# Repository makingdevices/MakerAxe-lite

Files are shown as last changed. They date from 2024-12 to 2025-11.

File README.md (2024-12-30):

<!-- Improved compatibility of back to top link: See: https://github.com/othneildrew/Best-README-Template/pull/73 -->

<!--
*** Thanks for checking out the Best-README-Template. If you have a suggestion
*** that would make this better, please fork the repo and create a pull request
*** or simply open an issue with the tag "enhancement".
*** Don't forget to give the project a star!
*** Thanks again! Now go create something AMAZING! :D
-->

<!-- PROJECT SHIELDS -->
<!--
*** I'm using markdown "reference style" links for readability.
*** Reference links are enclosed in brackets [ ] instead of parentheses ( ).
*** See the bottom of this document for the declaration of the reference variables
*** for contributors-url, forks-url, etc. This is an optional, concise syntax you may use.
*** https://www.markdownguide.org/basic-syntax/#reference-style-links
-->
[][ig-url]
[][yt-url]
[][sponsor-url]
[][stars-url]
[][issues-url]
[][linkedin-url]

<!-- PROJECT LOGO -->
<br />
<div align="center">
  <a href="https://makingdevices.com/links/">
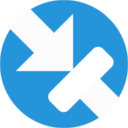
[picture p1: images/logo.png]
    
  </a>

<h3 align="center">Making Devices</h3>

  <p align="center">
    Open Source projects where we struggle with engineering, electronics, coding and who knows what else... MakerAxe-lite is the foundation for new BTC miners and exciting hardware in the future. 
  </p>
</div>

<!-- TABLE OF CONTENTS -->
<details>
  <summary>Table of Contents</summary>
  <ol>
    <li>
      <a href="#about-the-project">About The Project</a>
      <ul>
        <li><a href="#built-with">Built With</a></li>
      </ul>
    </li>
    <li>
      <a href="#Build-one">Build one</a>
      <ul>
      </ul>
    </li>
    <li><a href="#goals">Goals</a></li>
    <li><a href="#features">Features</a></li>
    <li><a href="#roadmap">Roadmap</a></li>
    <li><a href="#license">License</a></li>
    <li><a href="#contact">Contact</a></li>
    <li><a href="#tools">Tools</a></li>
    <li><a href="#Sponsor">Sponsor</a></li>
  </ol>
</details>

<!-- ABOUT THE PROJECT -->
## About The Project

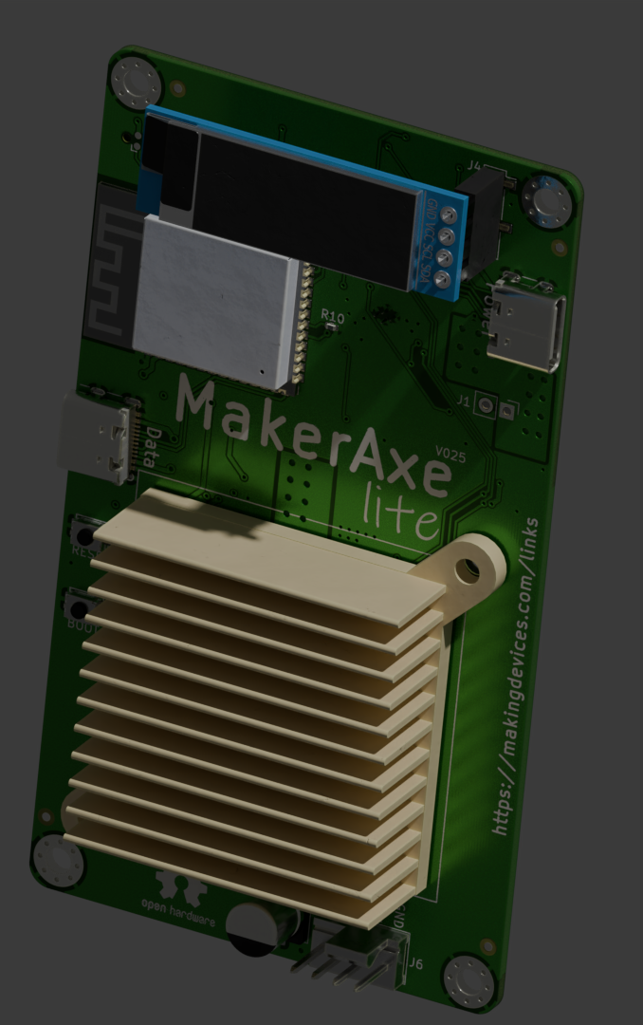
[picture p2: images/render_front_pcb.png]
Bytes Counter Shot
[](https://makingdevices.com/)

```
Open Source is Intrinsic to Bitcoin
```

This is the motto you will see at the top of the [Bitaxe repository](https://github.com/skot/bitaxe), and it’s the reason Why MakerAxe-Lite was created.

MakerAxe Lite is the first attempt to extract the essentials of Bitaxe, reduce it to the minimum, and create a foundation for building new and exciting hardware in the future.

The project modifies the original hardware with the following changes:

1. The screen is not needed, as you now have AxeOS. Therefore, the screen will be removed (DNP) to reduce energy consumption and costs.
2. The 4-layer PCB is reduced to a 2-layer PCB, decreasing the cost of the PCB.
3. The 5V barrel input connector is replaced with USB PD. The voltage (20V, 15V, or 12V) is yet to be decided. This change ensures compatibility with recycled and reused phone or laptop chargers.
4. A LED has been added for blinking status and debug purposes.
5. Software compatibility with the stock [ESP-miner AxeOS](https://github.com/skot/ESP-Miner) (aside from the LED indicator).

<p align="right">(<a href="#readme-top">back to top</a>)</p>

### Built With

[][ESP32-url]

[][kicad-url]
[][sponsor-url]

<p align="right">(<a href="#readme-top">back to top</a>)</p>

<!-- GETTING STARTED -->

## Build one
The project is yet to be finished. Should you want to reproduce it, be careful. 

1. Get the gerber files for the latest version: [MakerAxe-lite V025](/Gerber/makeraxe-litev025.zip) 
2. Send them to a PCB manufacturer ([Our Sponsor is PCBWAY][sponsor-url])
3. Schematic (?)

YET TO BE COMPLETED.

<p align="right">(<a href="#readme-top">back to top</a>)</p>

<!-- GOALS -->
## Goals
- **Standalone**: can mine directly to your pool over WiFi. No External computer needed.
- **Embedded**: low cost, low maintenance, high availability, high reliability, low power.
- **ASIC**: based on the very, very efficient BM1366 from Bitmain.
- **Versatile**: solo/pool mining, autotune power/heat/efficiency.
- **Open Source**: All design files are provided.

<p align="right">(<a href="#readme-top">back to top</a>)</p>

<!-- FEATURES -->
## Features
- **ESP32-S3-WROOM-1** wifi microcontroller on board
- **TI TPS40305** buck regulator steps down the input voltage to power the BM1366
- **Maxim DS4432U+** current DAC digitally adjusts the BM1366 core voltage from 0.04V to 2.4V
- **TI INA260** power meter measures the input voltage and current of the miner
- **Microchip EMC2101** PWM controls the fan and monitors tach output. BM1366 doesn't support die temp, but we have it placed super close to the ASIC so we can use the internal temp feature.
- Enjoy :D!

<p align="right">(<a href="#readme-top">back to top</a>)</p>

<!-- ROADMAP -->
## Roadmap

- [X] Design the V025 prototype board.
- [ ] Complete the schematic and BoM files with LCSC&DK codes. 
- [ ] Order/Assembly the V025 prototype board.
- [ ] Validate V025 revision
  - [ ] Check that USB PD Works (12V, 15V, 20V)
  - [ ] Check the ESP32 can be programmed. 
  - [ ] AxeOS Self-testing is OK.
  - [ ] Solder the ASIC and check temperatures.
  - [ ] Characterize the overall efficiency.
  - [ ] Stress the buck converter to see if it is enough for next projects.
  - [ ] Explore alternatives to eliminate 5V rail.
  - [ ] Develop firmware so the LED can be used. Merge to ESP-miner if possible
- [ ] Validate the complete design + order PCBA 

See the [open issues](https://github.com/makingdevices/MakerAxe-lite/issues) for a full list of proposed features (and known issues).

State: Project <b>ONGOING</b> - 26/12/2024

Priority: <b>High</b>

<p align="right">(<a href="#readme-top">back to top</a>)</p>

<!-- LICENSE -->
## License

Distributed under three licenses:
- [Hardware](/License/HW_cern_ohl_s_v2.pdf)
- [Software](/License/SW_GPLv3.0.txt)
- [Documentation](/License/Documentation_CC-BY-SA-4.0.txt)

OSHWA License: Not Finished

[GPL v3 License][license-url] 
<p align="right">(<a href="#readme-top">back to top</a>)</p>

<!-- CONTACT -->
## Contact

Making Devices - [@MakingDevices](https://www.instagram.com/makingdevices/)

Project Link: [https://github.com/makingdevices/MakerAxe-lite](https://github.com/makingdevices/MakerAxe-lite)

Other Links: [LinkTree](https://makingdevices.com/links/)

<!-- Tools -->
## Tools

During the realization of this project, you may need tools to assemble the PCB, solder components, and more.

These are the tools we've tested and currently have in our lab, so feel free to check them out if needed. Keep in mind that, even if prices are the same, you can support us in continuing to develop projects like this through the Amazon Influencer Program. Thank you!

- Microscope for smd soldering: [LinkMicro 246ms](https://amzn.to/3ZMVvwG)
- My solder paste: [ChipQuik LowTemp](https://amzn.to/3ZPYBjz)
- My soldering station with power supply: [Yihua 853D](https://amzn.to/3DwH0Wh)

<!-- Sponsor -->
## Sponsors

[PCBWAY](https://www.pcbway.com/?from=makingdevices) is the most professional PCB manufacturer for prototyping and low-volume production to work with in the world. With more than a decade in the field, They are committed to meeting the needs of their customers from different industries in terms of quality, delivery, cost-effectiveness and any other demanding requests. As Sponsor of Making Devices, they will be in charge of all the PCBs for MDV, allowing both of us to grow together in a long term partnership. We hope you take them into account for your both personal and professional prototypes or products.

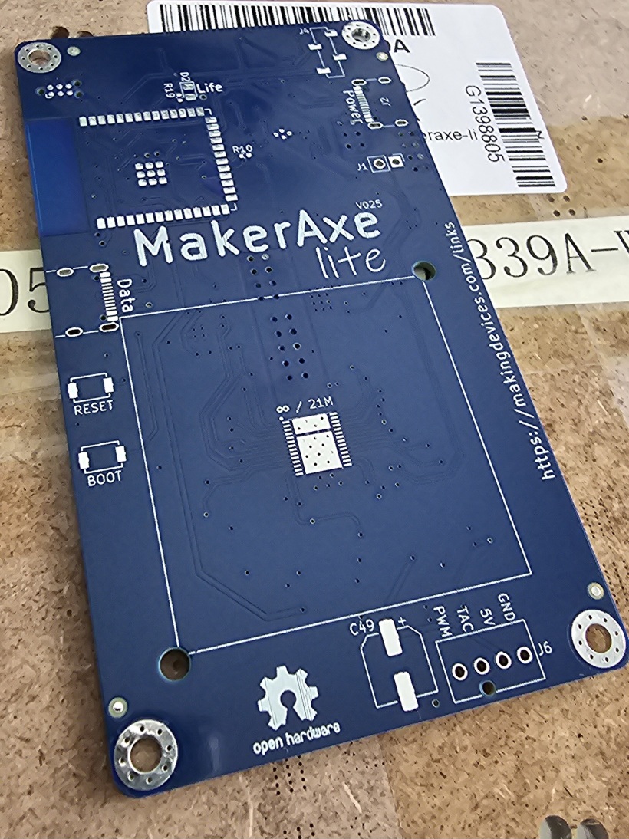
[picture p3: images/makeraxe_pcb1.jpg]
Sponsor Shot
[][sponsor-url]

<p align="right">(<a href="#readme-top">back to top</a>)</p>

<!-- MARKDOWN LINKS & IMAGES -->
<!-- https://www.markdownguide.org/basic-syntax/#reference-style-links -->
[contributors-shield]: https://img.shields.io/github/contributors/makingdevices/MakerAxe-lite.svg?style=for-the-badge
[contributors-url]: https://github.com/makingdevices/MakerAxe-lite/graphs/contributors
[forks-shield]: https://img.shields.io/github/forks/makingdevices/MakerAxe-lite.svg?style=for-the-badge
[forks-url]: https://github.com/makingdevices/MakerAxe-lite/network/members
[stars-shield]: https://img.shields.io/github/stars/makingdevices/MakerAxe-lite.svg?style=for-the-badge
[stars-url]: https://github.com/makingdevices/MakerAxe-lite/stargazers
[issues-shield]: https://img.shields.io/github/issues/makingdevices/MakerAxe-lite.svg?style=for-the-badge
[issues-url]: https://github.com/makingdevices/MakerAxe-lite/issues
[license-shield]: /images/license.png
[license-url]: https://github.com/makingdevices/MakerAxe-lite/tree/main/License
[linkedin-shield]: https://img.shields.io/badge/-LinkedIn-black.svg?style=for-the-badge&logo=linkedin&colorB=555
[linkedin-url]: https://www.linkedin.com/company/making-devices/
[sponsor-shield]: https://img.shields.io/badge/SPONSOR-PCBWAY-black.svg?style=for-the-badge&colorB=1200
[sponsor-url]: https://www.pcbway.com/?from=makingdevices
[sponsor-screenshot]: /images/PCB_sponsor.png
[sponsor-pcb-1]: /images/makeraxe_pcb1.jpg
[sponsor-wurth-1]: /images/wurth_1.gif
[sponsor-wurth-3]: /images/wurth_3.jpg
[sponsor-url-wurth]: https://www.we-online.com/en
[product-screenshot]: images/render_front_pcb.png
[ESP32]: https://img.shields.io/badge/ESP32_S3-7c0a02?style=for-the-badge
[ESP32-url]: https://www.espressif.com/sites/default/files/documentation/esp32-s3-wroom-1_wroom-1u_datasheet_en.pdf
[kicad-shield]: https://img.shields.io/badge/kicad-0b03fc?style=for-the-badge&logo=kicad&logoColor=white
[kicad-url]: https://www.kicad.org/
[YT-screenshot]: images/YT_assembly.PNG
[sponsor-icon]:  https://img.shields.io/badge/-PCBWAY-black.svg?style=for-the-badge&colorB=1200
[ig-shield]: https://img.shields.io/badge/instagram-a83297?style=for-the-badge&logo=instagram&logoColor=white
[ig-url]: https://www.instagram.com/makingdevices/
[yt-shield]: https://img.shields.io/badge/youtube-ff0000?style=for-the-badge&logo=youtube&logoColor=white
[yt-url]: https://www.youtube.com/@MakingDevices
[MPLAB-C]: https://img.shields.io/badge/MPLAB%20C18-DD0031?style=for-the-badge&logo=C&logoColor=white
[Arduino]: https://img.shields.io/badge/ARDUINO-00878F?style=for-the-badge&logo=arduino&logoColor=white
[wurth-icon]: https://img.shields.io/badge/Wurth%20elektronik-FF0031?style=for-the-badge&logoColor=white
[Arduino-url]: https://www.arduino.cc/
[MPLAB-C-url]: https://www.microchip.com/en-us/development-tool/SW006011
[Svelte.dev]: https://img.shields.io/badge/Svelte-4A4A55?style=for-the-badge&logo=svelte&logoColor=FF3E00
[Svelte-url]: https://svelte.dev/
[Laravel.com]: https://img.shields.io/badge/Laravel-FF2D20?style=for-the-badge&logo=laravel&logoColor=white
[Laravel-url]: https://laravel.com
[Bootstrap.com]: https://img.shields.io/badge/Bootstrap-563D7C?style=for-the-badge&logo=bootstrap&logoColor=white
[Bootstrap-url]: https://getbootstrap.com
[JQuery.com]: https://img.shields.io/badge/jQuery-0769AD?style=for-the-badge&logo=jquery&logoColor=white
[JQuery-url]: https://jquery.com

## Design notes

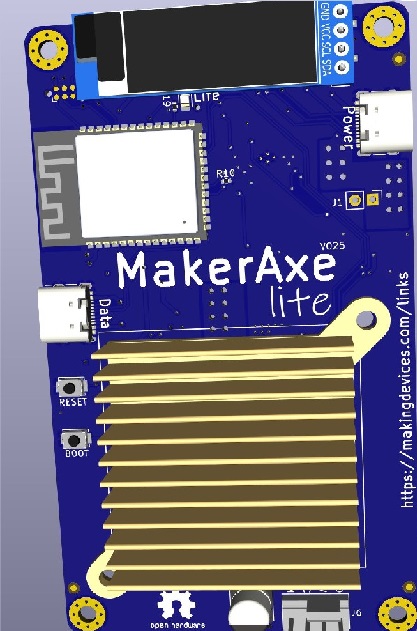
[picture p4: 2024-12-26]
images/screenshot.jpg

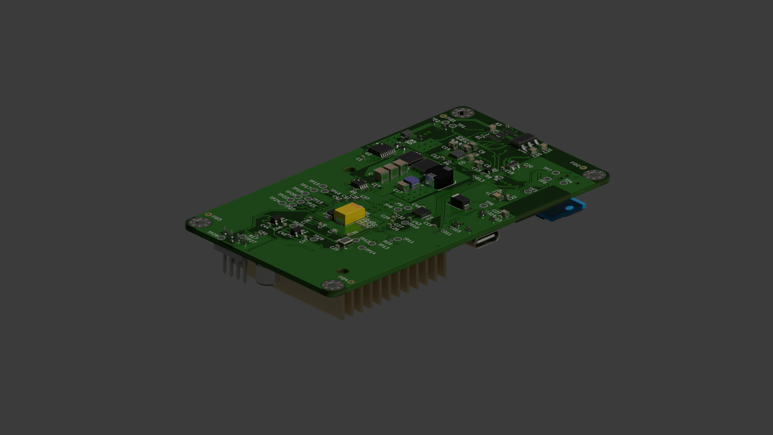
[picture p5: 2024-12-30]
images/render_back_pcb.png

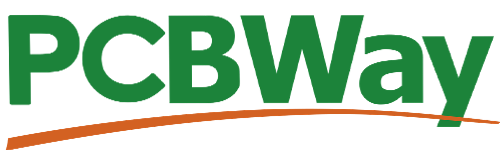
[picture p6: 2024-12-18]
images/PCB_sponsor.png

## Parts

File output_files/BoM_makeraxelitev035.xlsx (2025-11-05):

PCB Parts
Reference | Value | Datasheet | Footprint | Qty | Unit Price | Total Price | Generic? | LCSC ref | LCSC | Digikey Ref | Digikey | DNP
C1,C15,C18,C19,C20,C26,C27,C28,C29,C30,C32,C34,C35,C37,C38,C39,C40,C41,C42,C44,C45,C46,C47 | 1uF - 50V |  | Capacitor_SMD:C_0402_1005Metric | 23 | $0.0229 | $0.5267 | Yes | C1518208 | https://www.lcsc.com/product-detail/Multilayer-Ceramic-Capacitors-MLCC-SMD-SMT_Murata-Electronics-GRM155R61H105KE05D_C1518208.html
C2,C3,C4 | 47uF - 25V | ~ | Capacitor_SMD:C_1210_3225Metric | 3 | $0.3168 | $0.9504 | Yes | C90142 | https://www.lcsc.com/product-detail/Multilayer-Ceramic-Capacitors-MLCC-SMD-SMT_Taiyo-Yuden-TMK325ABJ476MM-P_C90142.html
C5,C7 | 1uF -50V | ~ | Capacitor_SMD:C_0805_2012Metric | 2 | $0.0084 | $0.0168 | Yes | C28323 | https://www.lcsc.com/product-detail/Multilayer-Ceramic-Capacitors-MLCC-SMD-SMT_Samsung-Electro-Mechanics-CL21B105KBFNNNE_C28323.html
C6 | 3.3nF -50V | ~ | Capacitor_SMD:C_0402_1005Metric | 1 | $0.0116 | $0.0116 | Yes | C1518207 | https://www.lcsc.com/product-detail/Multilayer-Ceramic-Capacitors-MLCC-SMD-SMT_Murata-Electronics-GRM1555C1H332JE01D_C1518207.html
C8 | 180pF -50V | ~ | Capacitor_SMD:C_0805_2012Metric | 1 | $0.0082 | $0.0082 | Yes | C113826 | https://www.lcsc.com/product-detail/Multilayer-Ceramic-Capacitors-MLCC-SMD-SMT_YAGEO-CC0805JRNPO9BN181_C113826.html
C9 | 1.5nF - 50V | ~ | Capacitor_SMD:C_0805_2012Metric | 1 | $0.0050 | $0.0050 | Yes | C107142 | https://www.lcsc.com/product-detail/Multilayer-Ceramic-Capacitors-MLCC-SMD-SMT_YAGEO-CC0805KRX7R9BB152_C107142.html
C52 | 0.47uF | ~ | Capacitor_SMD:C_1206_tantalum | 1 | $0.0113 | $0.0113 | Yes |  | https://www.digikey.es/es/products/detail/kemet/T491A474K025AT7280/8612898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
C53 | 22uF | https://content.kemet.com/datasheets/KEM_T2009_T495.pdf | Capacitor_SMD:C_2312_tantalum | 1 | $0.3900 | $0.3900 | Yes | C1953042 | https://www.lcsc.com/product-detail/Tantalum-Capacitors_KEMET-T495C226K025ATE300_C1953042.html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
C12,C23,C25,C31,C33,C43,C48,C50,C51 | 0.1uF |  | Capacitor_SMD:C_0402_1005Metric | 9 | $0.0025 | $0.0225 | Yes | C131394 | https://www.lcsc.com/product-detail/Multilayer-Ceramic-Capacitors-MLCC-SMD-SMT_YAGEO-CC0402KRX7R9BB104_C131394.html
C13,C21 | 10uF |  | Capacitor_SMD:C_0805_2012Metric | 2 | $0.0618 | $0.1236 | Yes | C440198 | https://www.lcsc.com/product-detail/Multilayer-Ceramic-Capacitors-MLCC-SMD-SMT_Murata-Electronics-GRM21BR61H106KE43L_C440198.html
C14 | 470pF | ~ | Capacitor_SMD:C_0805_2012Metric | 1 | $0.0078 | $0.0078 | Yes | C1822 | https://www.lcsc.com/product-detail/Multilayer-Ceramic-Capacitors-MLCC-SMD-SMT_FH-Guangdong-Fenghua-Advanced-Tech-0805CG471J500NT_C1822.html
C16 | 220uF | https://media.digikey.com/pdf/Data%20Sheets/Panasonic%20Capacitors%20PDFs/TPE_Series_POSCAP_Rev02_Oct_2017.pdf | bitaxe:CAP_2R5TPE220MAFB | 1 | $0.2538 | $0.2538 | Alternative?? | C2976916 | https://www.lcsc.com/product-detail/Tantalum-Capacitors_CEC-Shenzhen-Zhenhua-XinYun-Elec-CA45B-B-6-3V-220UF-M_C2976916.html
C17 | 100uF - 10V | ~ | Capacitor_SMD:C_1206_3216Metric | 1 | $0.1566 | $0.1566 | Yes | C883598 | https://www.lcsc.com/product-detail/Multilayer-Ceramic-Capacitors-MLCC-SMD-SMT_Murata-Electronics-GRM31CR61A107MEA8L_C883598.html
C22,C24 | 6.8pF | ~ | Capacitor_SMD:C_0402_1005Metric | 2 | $0.0012 | $0.0024 | Yes | C5186887 | https://www.lcsc.com/product-detail/Multilayer-Ceramic-Capacitors-MLCC-SMD-SMT_Chinocera-HGC0402G06R8C500NTEJ_C5186887.html
C36 | 330uF | ~ | Capacitor_Tantalum_SMD:CP_EIA-7343-31_Kemet-D_Pad2.25x2.55mm_HandSolder | 1 | $1.0355 | $1.0355 |  | C1965141 | https://www.lcsc.com/product-detail/Tantalum-Capacitors_Vishay-Intertech-293D337X9010E2TE3_C1965141.html
C49 | 220uF | ~ | Capacitor_SMD:CP_Elec_6.3x7.7 | 1 | $0.0834 | $0.0834 | Alternative?? | C25503905 | https://www.lcsc.com/product-detail/Polymer-Aluminum-Capacitors_ChuangHui-Electronics-SS221M160E7R7R4Z00ZZ_C25503905.html
D1 | SS310 | https://www.mccsemi.com/pdf/Products/SK32A-L-SK310A-L(DO-214AC).pdf | Diode_SMD:D_SMA | 1 | $0.0650 | $0.0650 | Yes | C5140021 | https://www.lcsc.com/product-detail/Diodes-General-Purpose_MSKSEMI-SS310_C5140021.html?s_z=n_SS310
D2 | LED | ~ | LED_SMD:LED_0805_2012Metric_Pad1.15x1.40mm_HandSolder | 1 | $0.0607 | $0.0607 | Yes | C264427 | https://www.lcsc.com/product-detail/LED-Indication-Discrete_Everlight-Elec-17-215-GVC-CF2H1AX-3T-D_C264427.html
D3 | PTVS20VS1UR,115 | https://assets.nexperia.com/documents/data-sheet/PTVSXS1UR_SER.pdf | bitaxe:SOD123W | 1 | $0.1877 | $0.1877 |  | C461164 | https://www.lcsc.com/product-detail/ESD-and-Surge-Protection-TVS-ESD_Nexperia-PTVS20VS1UR-115_C461164.html
IC1 | CH224K | https://datasheet.lcsc.com/lcsc/2204251615_WCH-Jiangsu-Qin-Heng-CH224K_C970725.pdf | SOP100P600X180-11N | 1 | $0.4775 | $0.4775 |  | C970725 | https://www.lcsc.com/product-detail/USB-PD_WCH-Jiangsu-Qin-Heng-CH224K_C970725.html
J2,J5 | USB_C_Receptacle_USB2.0 | https://gct.co/connector/usb4105 | Connector_USB:USB_C_Receptacle_GCT_USB4105-xx-A_16P_TopMnt_Horizontal | 2 | $0.7500 | $1.5000 |  |  |  | 2073-USB4105-GF-ACT-ND | https://www.digikey.es/es/products/detail/gct/USB4105-GF-A/11198441
J4 | Conn_01x04 | ~ | Connector_PinSocket_2.54mm:PinSocket_1x04_P2.54mm_Vertical_SMD_Pin1Right | 1 | $0.6000 | $0.6000 |  |  |  | NPTC041KFXC-RC
J6 | Conn_01x04 | ~ | bitaxe:470531000 | 1 | $0.1897 | $0.1897 | Yes | C240840 | https://www.lcsc.com/product-detail/Wire-To-Board-Connector_MOLEX-470531000_C240840.html
L1 | SPM6530T-R47M-HZ | https://product.tdk.com/system/files/dam/doc/product/inductor/inductor/smd/catalog/inductor_automotive_power_spm6530-hz_en.pdf | SPM6530 | 1 | $0.3729 | $0.3729 | Alternative?? | C3040345 | https://www.lcsc.com/product-detail/Power-Inductors_cjiang-Changjiang-Microelectronics-Tech-FAUL0630-R47MT_C3040345.html
Q1 | 2N7002K | https://www.diodes.com/assets/Datasheets/ds30896.pdf | Package_TO_SOT_SMD:SOT-323_SC-70 | 1 | $0.1104 | $0.1104 | Yes | C266797 | https://www.lcsc.com/product-detail/MOSFETs_onsemi-2N7002KW_C266797.html
Q2,Q3 | CSD17311Q5 | https://www.ti.com/lit/ds/symlink/csd17311q5.pdf | bitaxe:CSD17311Q5 | 2 | $1.1519 | $2.3038 |  | C139640 | https://www.lcsc.com/product-detail/MOSFETs_Texas-Instruments-CSD17311Q5_C139640.html
R1 | 1k | ~ | Resistor_SMD:R_0402_1005Metric | 1 | $0.0006 | $0.0006 | Yes | C106235 | https://www.lcsc.com/product-detail/Chip-Resistor-Surface-Mount_YAGEO-RC0402FR-071KL_C106235.html
R2 | 3.83k | ~ | Resistor_SMD:R_0402_1005Metric | 1 | $0.0005 | $0.0005 | Yes | C67236 | https://www.lcsc.com/product-detail/Chip-Resistor-Surface-Mount_UNI-ROYAL-Uniroyal-Elec-0402WGF3831TCE_C67236.html
R3,R8,R11,R13,R16,R18 | 10K | ~ | Resistor_SMD:R_0402_1005Metric | 6 | $0.0005 | $0.0030 | Yes | C60490 | https://www.lcsc.com/product-detail/Chip-Resistor-Surface-Mount_YAGEO-RC0402FR-0710KL_C60490.html
R4 | 4.12k | ~ | Resistor_SMD:R_0402_1005Metric | 1 | $0.0004 | $0.0004 | Yes | C327340 | https://www.lcsc.com/product-detail/Chip-Resistor-Surface-Mount_YAGEO-RC0402FR-074K12L_C327340.html
R5 | 1.33k | ~ | Resistor_SMD:R_0402_1005Metric | 1 | $0.0055 | $0.0055 | Yes | C400606 | https://www.lcsc.com/product-detail/Chip-Resistor-Surface-Mount_PANASONIC-ERJ2RKF1331X_C400606.html
R6 | 4.99k | ~ | Resistor_SMD:R_0402_1005Metric | 1 | $0.0005 | $0.0005 | Yes | C168233 | https://www.lcsc.com/product-detail/Chip-Resistor-Surface-Mount_Walsin-Tech-Corp-WR04X4991FTL_C168233.html
R7 | 3.32k | ~ | Resistor_SMD:R_0402_1005Metric | 1 | $0.0005 | $0.0005 | Yes | C60075 | https://www.lcsc.com/product-detail/Chip-Resistor-Surface-Mount_UNI-ROYAL-Uniroyal-Elec-0402WGF3321TCE_C60075.html
R9 | 80.6k | ~ | Resistor_SMD:R_0402_1005Metric | 1 | $0.0010 | $0.0010 | Yes | C227238 | https://www.lcsc.com/product-detail/Chip-Resistor-Surface-Mount_YAGEO-AC0402FR-0780K6L_C227238.html
R10 | 24k | ~ | Resistor_SMD:R_0402_1005Metric | 1 | $0.0005 | $0.0005 | Yes | C2933082 | https://www.lcsc.com/product-detail/Chip-Resistor-Surface-Mount_FOJAN-FRC0402F2402TS_C2933082.html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
R12 | 1M | ~ | Resistor_SMD:R_0402_1005Metric | 1 | $0.0005 | $0.0005 | Yes | C2909328 | https://www.lcsc.com/product-detail/Chip-Resistor-Surface-Mount_FOJAN-FRC0402F1004TS_C2909328.html
R14,R15 | 5.1k | ~ | Resistor_SMD:R_0402_1005Metric | 2 | $0.0005 | $0.0010 | Yes | C2906874 | https://www.lcsc.com/product-detail/Chip-Resistor-Surface-Mount_FOJAN-FRC0402F5101TS_C2906874.html
R17 | 5.6k | ~ | Resistor_SMD:R_0402_1005Metric | 1 | $0.0005 | $0.0005 | Yes | C2909364 | https://www.lcsc.com/product-detail/Chip-Resistor-Surface-Mount_FOJAN-FRC0402F5601TS_C2909364.html
R19 | 220 | ~ | Resistor_SMD:R_0402_1005Metric | 1 | $0.0004 | $0.0004 | Yes | C25151 | https://www.lcsc.com/product-detail/Chip-Resistor-Surface-Mount_UNI-ROYAL-Uniroyal-Elec-0402WGJ0221TCE_C25151.html
SW1,SW2 | GT-TC029B-H025-L1N | https://www.citrelay.com/Catalog%20Pages/SwitchCatalog/CS1213.pdf | bitaxe:SW_CS1213AGF260_CRS | 2 | $0.0582 | $0.1164 | Yes | C843669 | https://www.lcsc.com/product-detail/Tactile-Switches_G-Switch-GT-TC029B-H025-L1N_C843669.html
U2 | INA260 | http://www.ti.com/lit/ds/symlink/ina260.pdf | Package_SO:TSSOP-16_4.4x5mm_P0.65mm | 1 | $2.7437 | $2.7437 |  | C2155885 | https://www.lcsc.com/product-detail/Supervisor-and-Reset-ICs_Texas-Instruments-INA260AIPWR_C2155885.html
U3 | TS2940Cm50 | https://ms.componentsearchengine.com/Datasheets/2/TS2940CW33RPG.pdf | TO263-3 - Positive Electrode | 1 | $1.4822 | $1.4822 | Alternative?? | C13980 | https://www.lcsc.com/product-detail/Voltage-Regulators-Linear-Low-Drop-Out-LDO-Regulators_Texas-Instruments-LM2940SX-5-0-NOPB_C13980.html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
U4 | TPS40305 | https://www.ti.com/lit/ds/symlink/tps40303.pdf | bitaxe:TPS40305 | 1 | $1.7153 | $1.7153 | Alternative?? | C140285 | https://www.lcsc.com/product-detail/DC-DC-Converters_Texas-Instruments-TPS40305DRCR_C140285.html
U5 | DS4432U+ | https://datasheets.maximintegrated.com/en/ds/DS4432.pdf | Package_SO:TSSOP-8_3x3mm_P0.65mm | 1 | $3.3200 | $3.3200 |  | C7452688 |  | DS4432U+-ND | https://www.digikey.es/es/products/detail/analog-devices-inc-maxim-integrated/DS4432U/2062889
U6 | RT9080-33GJ5 | https://www.richtek.com/assets/product_file/RT9080/DS9080-05.pdf | bitaxe:RT9080-33GJ5 | 1 | $0.1031 | $0.1031 | Alternative?? | C841192 | https://www.lcsc.com/product-detail/Voltage-Regulators-Linear-Low-Drop-Out-LDO-Regulators_Richtek-Tech-RT9080-33GJ5_C841192.html
U7 | ESP32-S3-WROOM-1 | https://www.espressif.com/sites/default/files/documentation/esp32-s3-wroom-1_wroom-1u_datasheet_en.pdf | bitaxe:ESP32-S3-WROOM-1 | 1 | $4.0204 | $4.0204 | Alternative?? | C2913198 | https://www.lcsc.com/product-detail/WiFi-Modules_Espressif-Systems-ESP32-S3-WROOM-1-N8_C2913198.html
U8 | 25MHz | https://www.jauch.com/downloadfile/5ef1edcfb8e2f73163c8ce8009ef659d1/jo32-1.8-3.3v.pdf | bitaxe:O 25,0-JO32-B-1V3-1-T1-LF | 1 | $0.8700 | $0.8700 |  |  |  | 1908-O250-JO32-B-1V3-1-T1-LFDKR-ND | https://www.digikey.es/es/products/detail/jauch-quartz/O-25-0-JO32-B-1V3-1-T1-LF/10416083
U9 | BM1366_mode1 |  | bitaxe:BM1366 | 0 |  |  | Critic IC |  |  |  |  | DNP
U10 | TXB0104RGYR | https://www.ti.com/lit/ds/symlink/txb0104.pdf?HQS=dis-dk-null-digikeymode-dsf-pf-null-wwe&ts=1669420543825 | bitaxe:TXB0104 | 1 | $0.3702 | $0.3702 |  | C400708 | https://www.lcsc.com/product-detail/Translators-Level-Shifters_Texas-Instruments-TXB0104RGYR_C400708.html
U11 | MCP1824T-1802E | https://ww1.microchip.com/downloads/en/DeviceDoc/22070a.pdf | Package_TO_SOT_SMD:SOT-23-5 | 1 | $0.9269 | $0.9269 |  | C625462 | https://www.lcsc.com/product-detail/Voltage-Regulators-Linear-Low-Drop-Out-LDO-Regulators_Microchip-Tech-MCP1824T-1802E-OT_C625462.html | MCP1824T-1802E/OTCT-ND
U12 | MCP1824T-0802E | https://ww1.microchip.com/downloads/en/DeviceDoc/22070a.pdf | Package_TO_SOT_SMD:SOT-23-5 | 1 | $1.0740 | $1.0740 |  | C625460 | https://www.lcsc.com/product-detail/Power-Management-Specialized_Microchip-Tech-MCP1824T-0802E-OT_C625460.html | MCP1824T-0802E/OTCT-ND
U13 | EMC2101 | https://ww1.microchip.com/downloads/en/DeviceDoc/2101.pdf | Package_SO:TSSOP-8_3x3mm_P0.65mm | 1 |  | $0.0000 |  | C626967 | Out of stock | EMC2101-ACZL-DKR-ND | https://www.digikey.es/es/products/detail/microchip-technology/EMC2101-ACZL-TR/3872079
Y1 | 32.768kHz | https://www.sii.co.jp/en/quartz/files/2013/03/SC-32S_Leaflet_e20151217.pdf | bitaxe:SC32S-7PF20PPM | 1 | $0.1769 | $0.1769 | Yes | C97604 | https://www.lcsc.com/product-detail/Crystals_Seiko-SC-32S32-768kHz20PPM7pF_C97604.html
Total Parts: | 96
Total Cost: | $23.2154
Realistic cost: | $27.8585

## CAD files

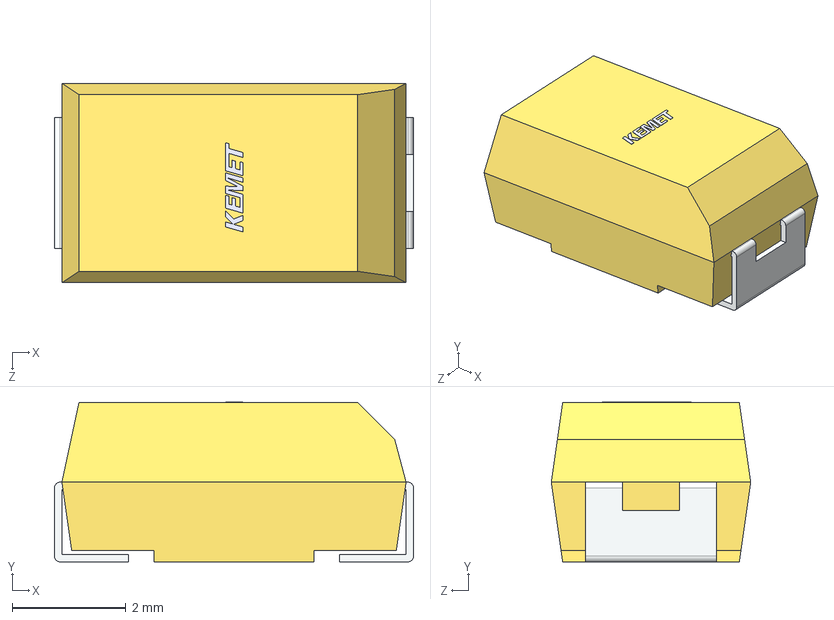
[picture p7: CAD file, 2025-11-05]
Kicad/3d/T495C226K025ATE300.stp
6.30 x 2.81 x 3.50 mm

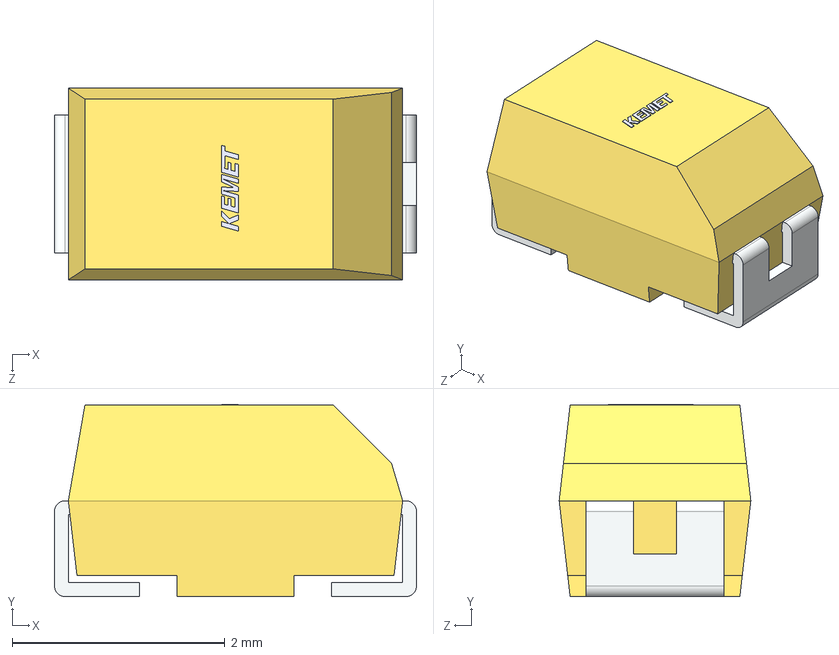
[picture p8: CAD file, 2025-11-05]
Kicad/3d/T491A474K025AT7280.stp
3.40 x 1.81 x 1.80 mm

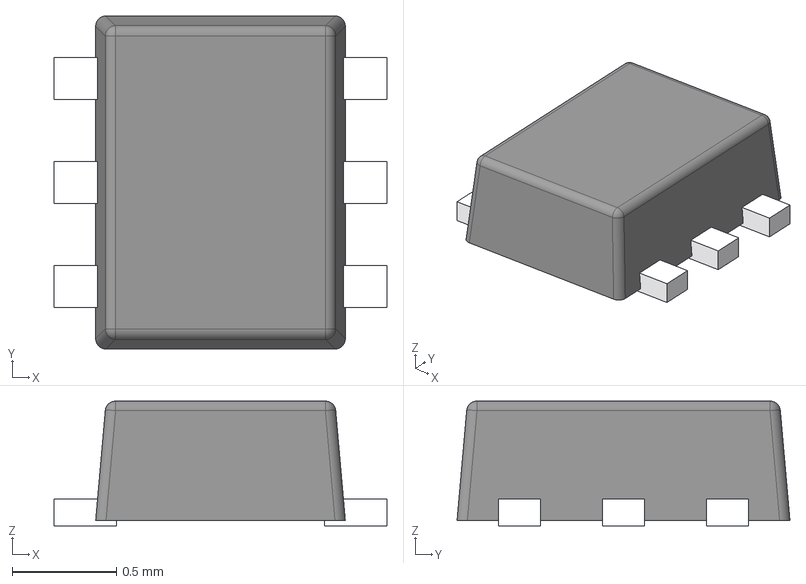
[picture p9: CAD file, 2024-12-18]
Kicad/3d/DRL0006A.stp
1.60 x 1.60 x 0.6 mm
FRAME-DRL0006A
BODY-SOT
PIN1-ID

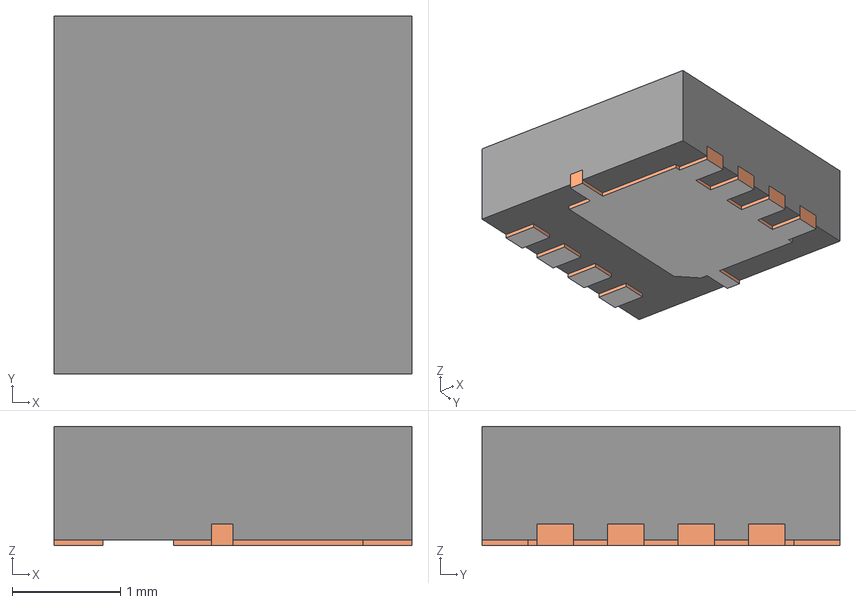
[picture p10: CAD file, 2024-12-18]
Kicad/3d/DQG0008A.stp
3.30 x 3.30 x 1.10 mm
BODY-SON
FRAME-DQG0008A
PIN1-ID

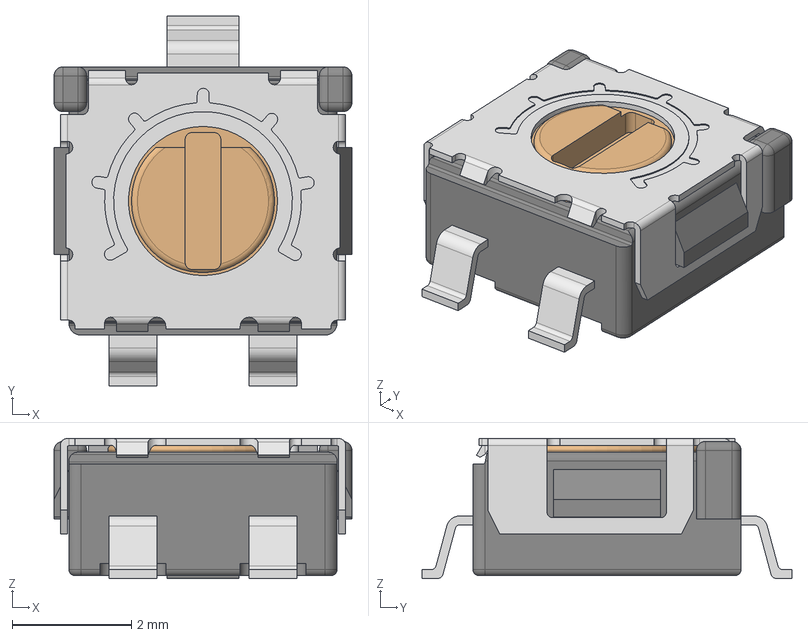
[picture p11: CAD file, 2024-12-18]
Kicad/3d/ST-4ETB2k_(202).stp
5.00 x 6.20 x 2.35 mm
ST-4EB_terminal_2
ST-4EB_terminal
ST-4EB_terminal_1
ST-4-dial2
ST-4EB10X(100)_body

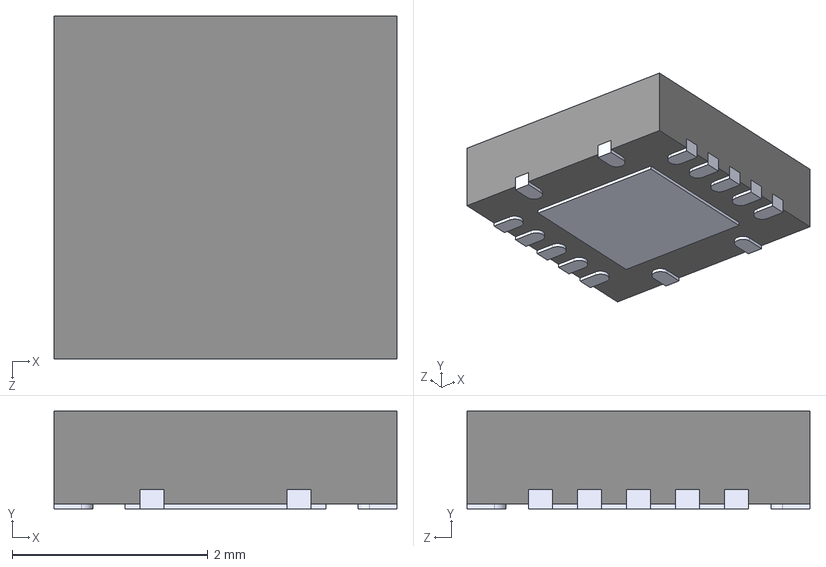
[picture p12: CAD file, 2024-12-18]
Kicad/3d/TXB0104RGYR.STEP
3.50 x 1.00 x 3.50 mm

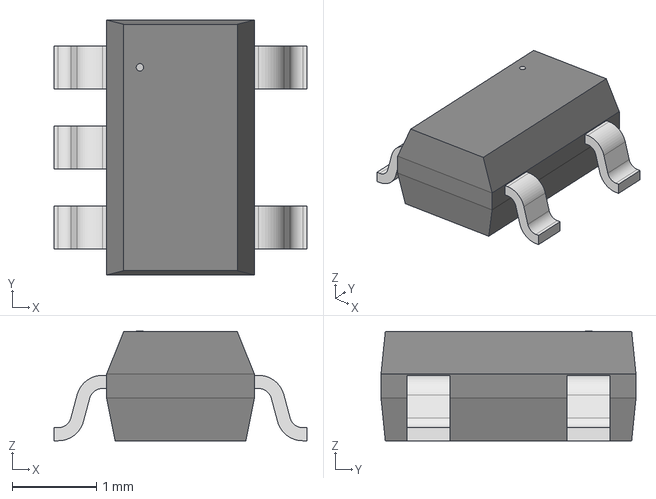
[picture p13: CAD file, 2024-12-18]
Kicad/3d/SOT-23-5_M5_MCH.step
3.00 x 3.02 x 1.30 mm

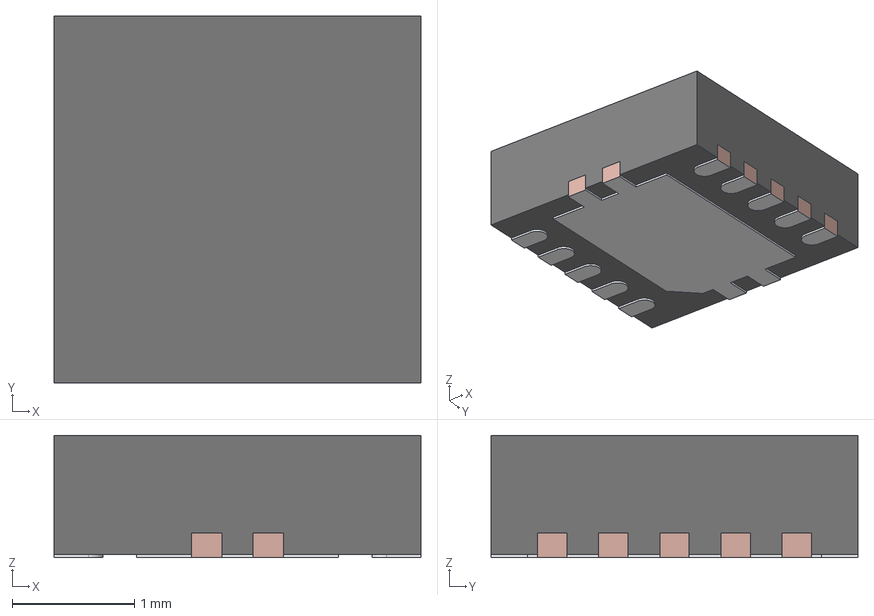
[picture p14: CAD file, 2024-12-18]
Kicad/3d/DRC0010J.stp
3.00 x 3.00 x 1.00 mm
BODY-SON
FRAME-DRC0010J

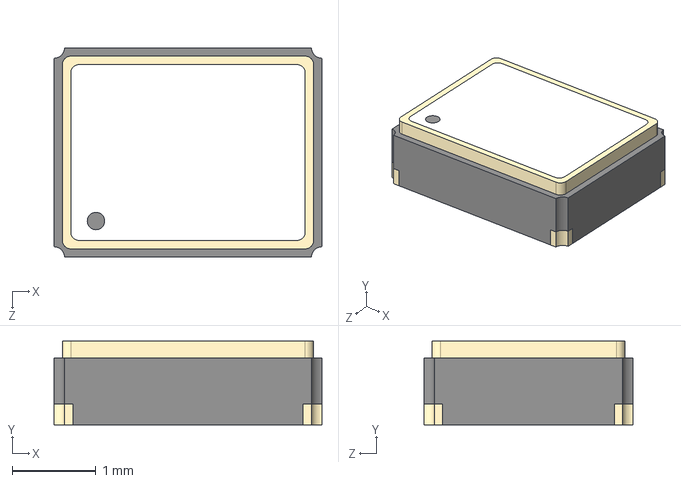
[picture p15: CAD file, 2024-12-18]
Kicad/3d/oscillator3.2x2.5.step
3.20 x 1.00 x 2.50 mm

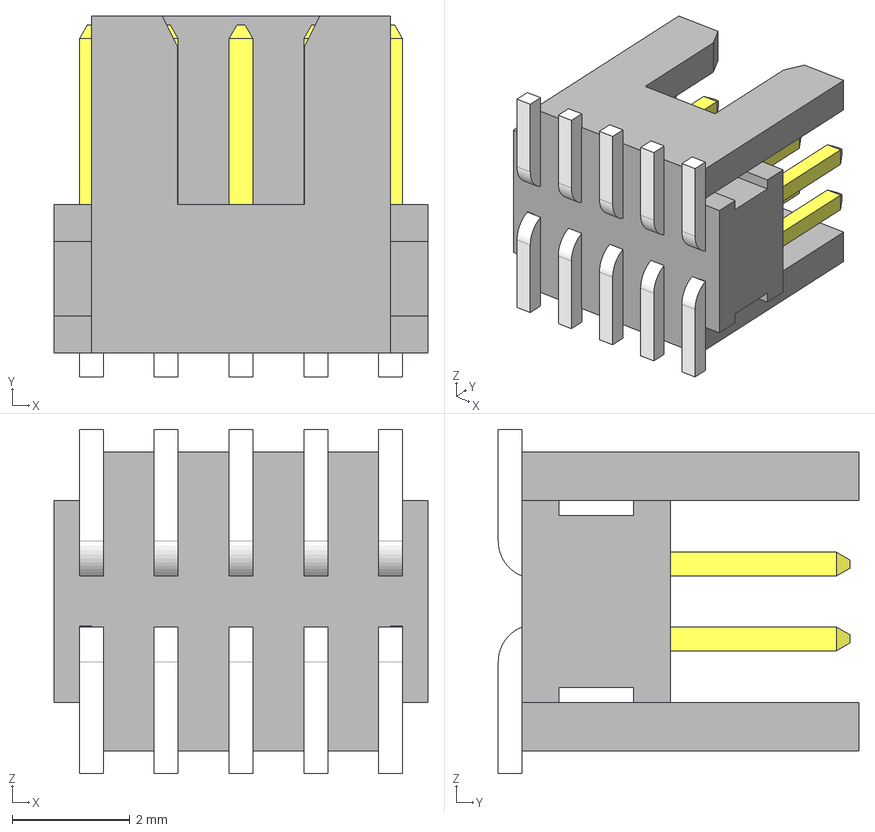
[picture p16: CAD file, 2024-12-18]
Kicad/3d/FTSH-105-01-F-DV-K.stp
6.35 x 6.12 x 5.84 mm
FTSH-105-01-F-DV-K_pins2
FTSH-105-01-F-DV-K_pins1
FTSH-105-01-F-DV-K_body

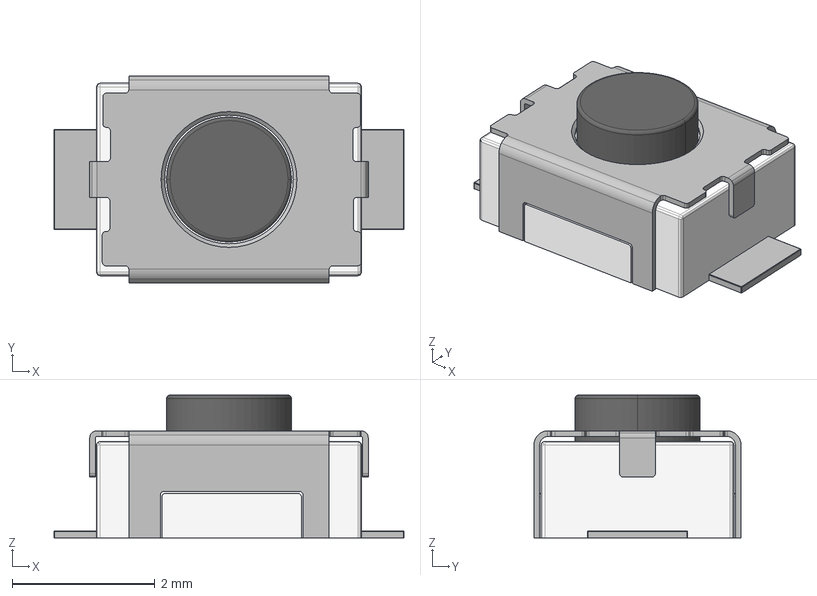
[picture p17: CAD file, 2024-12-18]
Kicad/3d/CS1213AG-tr.stp
4.90 x 2.90 x 2.00 mm

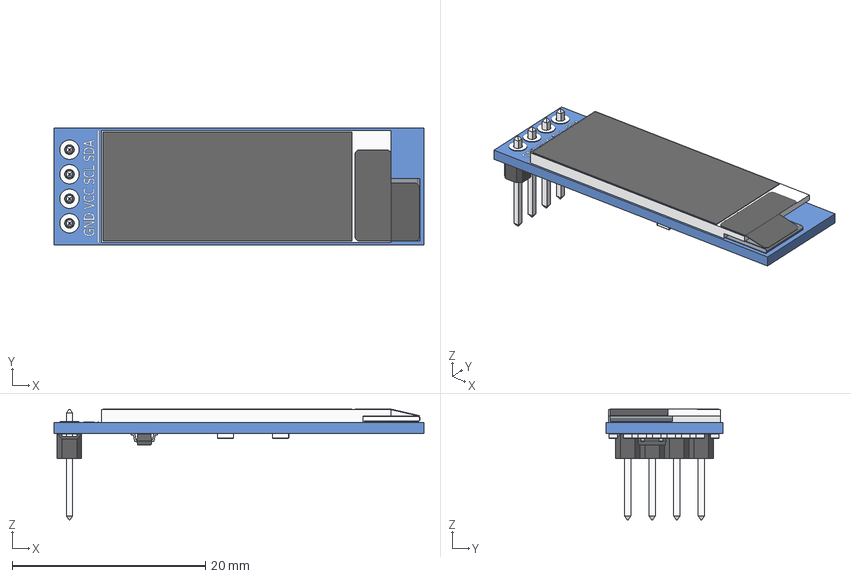
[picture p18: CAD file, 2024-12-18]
Kicad/3d/OLED_0.91_128x32.stp
38.3 x 12.1 x 11.5 mm
OLED_0.91_128x32
Pin Header 4 x 1 TH 2.54mm Pitch
RESC-0603 x 13
2SD0601A

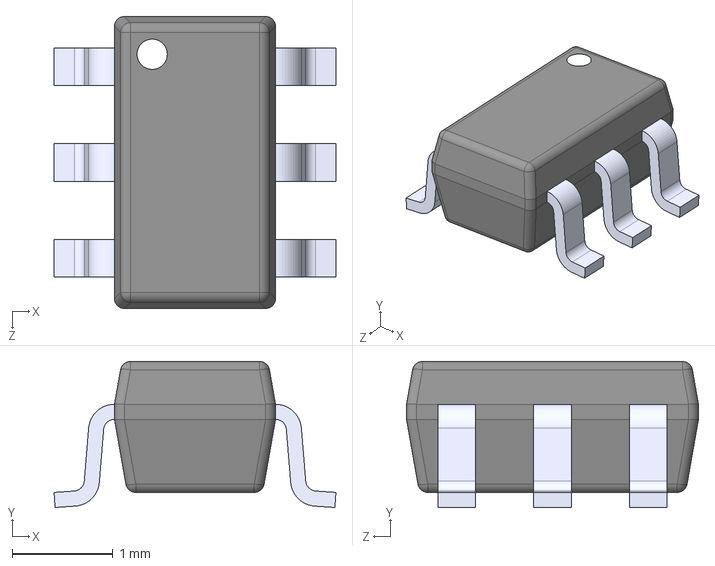
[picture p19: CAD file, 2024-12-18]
Kicad/3d/SN74AXC1T45DBVR.STEP
2.80 x 1.45 x 2.90 mm

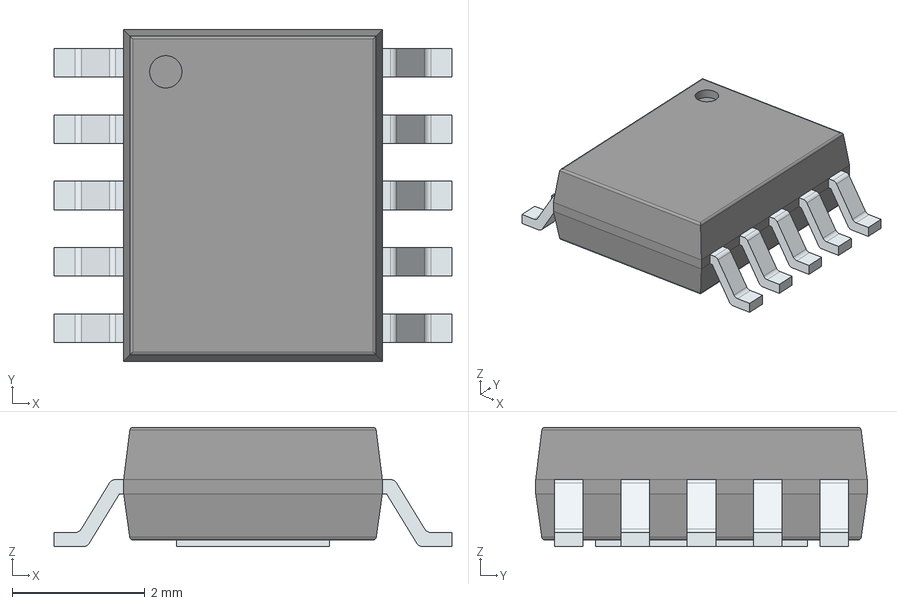
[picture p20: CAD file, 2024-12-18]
Kicad/3d/CH224K.stp
6.00 x 5.00 x 1.80 mm
PinsArrayLR
ThermalPad

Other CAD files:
Kicad/3d/ESP32-S3-WROOM-1-N8R2--3DModel-STEP-56544.STEP
Kicad/3d/PLCC6_LED_3_5X3_4X2_8_CRW.step
Kicad/3d/CUI_DEVICES_PJ-002AH.step
Kicad/3d/XRCGB27M120F3M10R0_MUR.step
Kicad/3d/21-0164B_L622-1_MXM.step
Kicad/3d/2R5TPE220MAFB.step
Kicad/3d/470531000.stp
Kicad/3d/54-00164.STEP
Kicad/3d/Bitaxe_Heatsink.step
Kicad/3d/CUI_DEVICES_PJ-037AH.step
Kicad/3d/CX3225SB16000H0FLJCC.STEP
Kicad/3d/Cree_PLCC6.stp
Kicad/3d/DISST7789-176x320.STEP
Kicad/3d/DQH0008A.stp
Kicad/3d/FP1006V2-R.STEP
Kicad/3d/IHLP2020CZ.step
Kicad/3d/PTVS20VS1UR,115.stp
Kicad/3d/SMV_z90.stp
Kicad/3d/SPM6530T-R47M-HZ.stp
Kicad/3d/SW_CS1213AGF260_CRS.step
Kicad/3d/TS2940CW33_RPG.stp
Kicad/3d/TSOT-23-5_RIT.step
Kicad/3d/USB_10118193-0001LF.STEP
Kicad/3d/XTAL_SC32S-7PF20PPM_EPS.step
Kicad/3d/c-63862-1-r-3d.stp

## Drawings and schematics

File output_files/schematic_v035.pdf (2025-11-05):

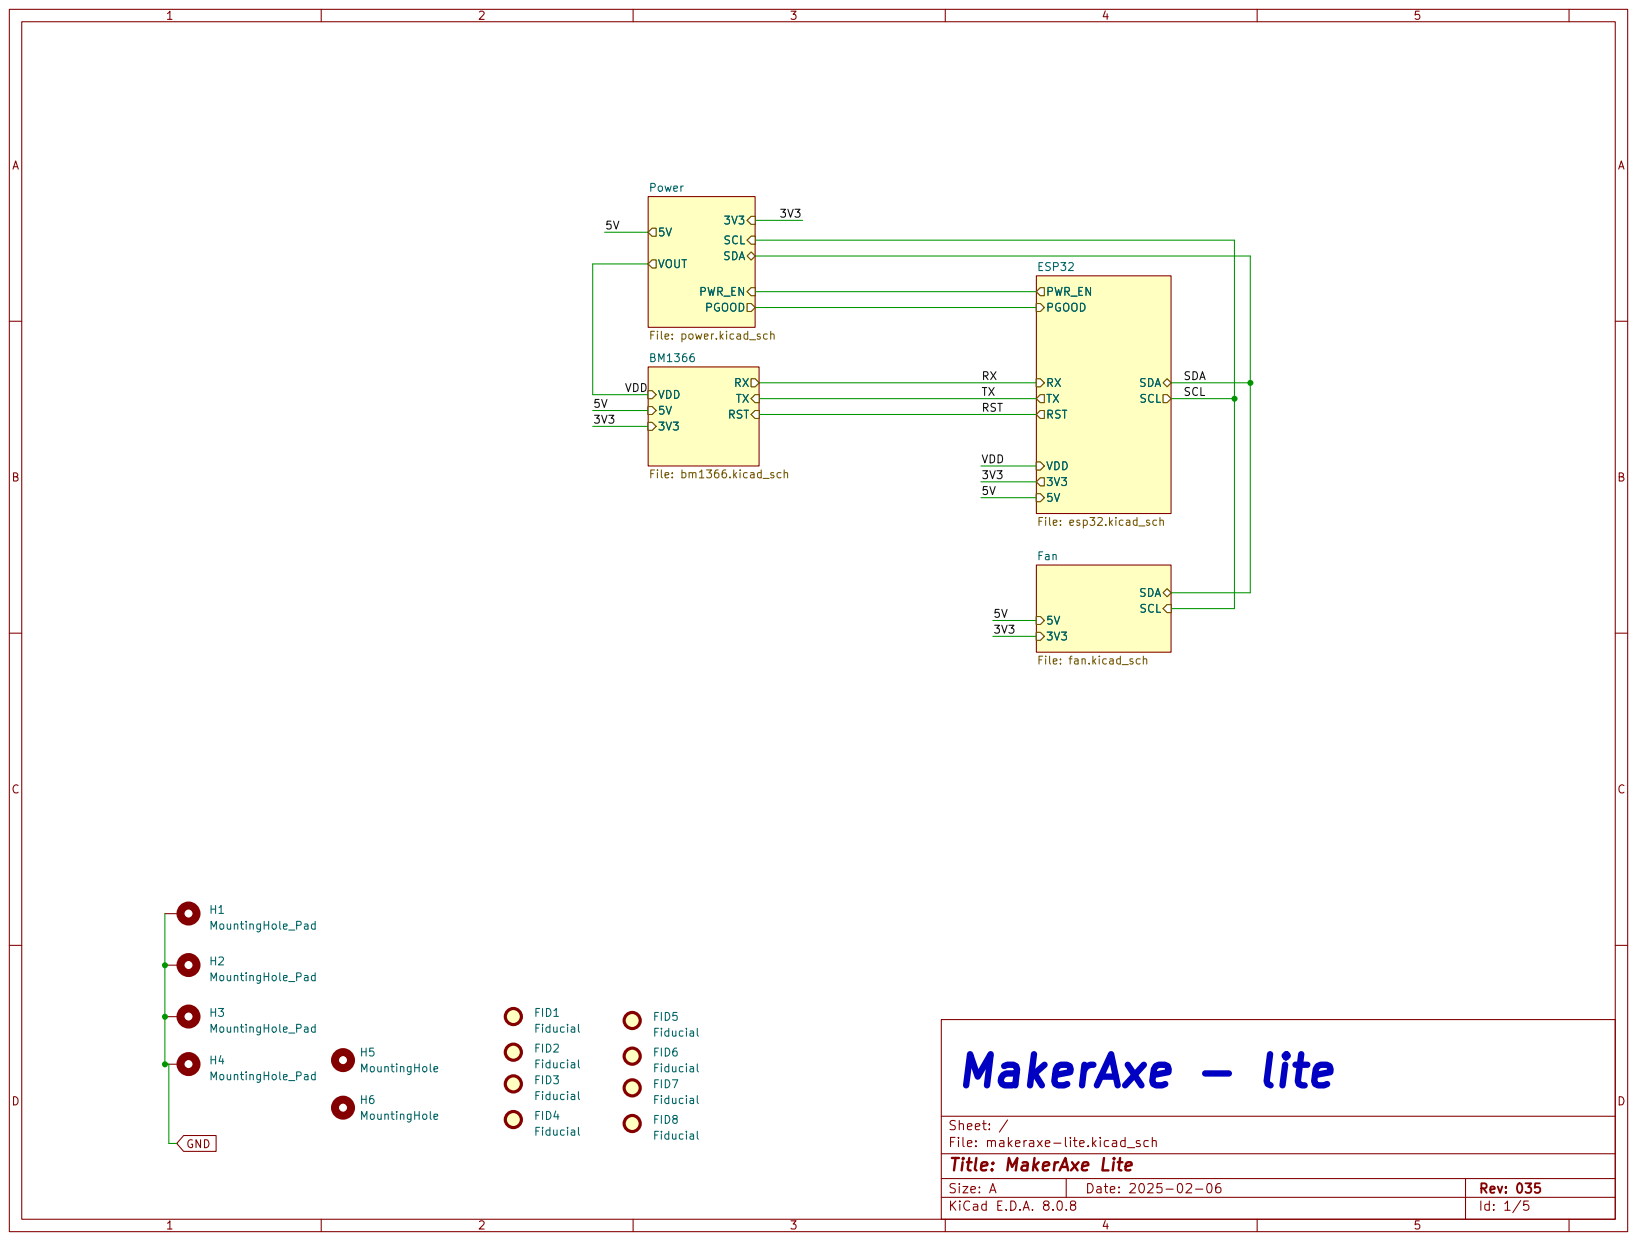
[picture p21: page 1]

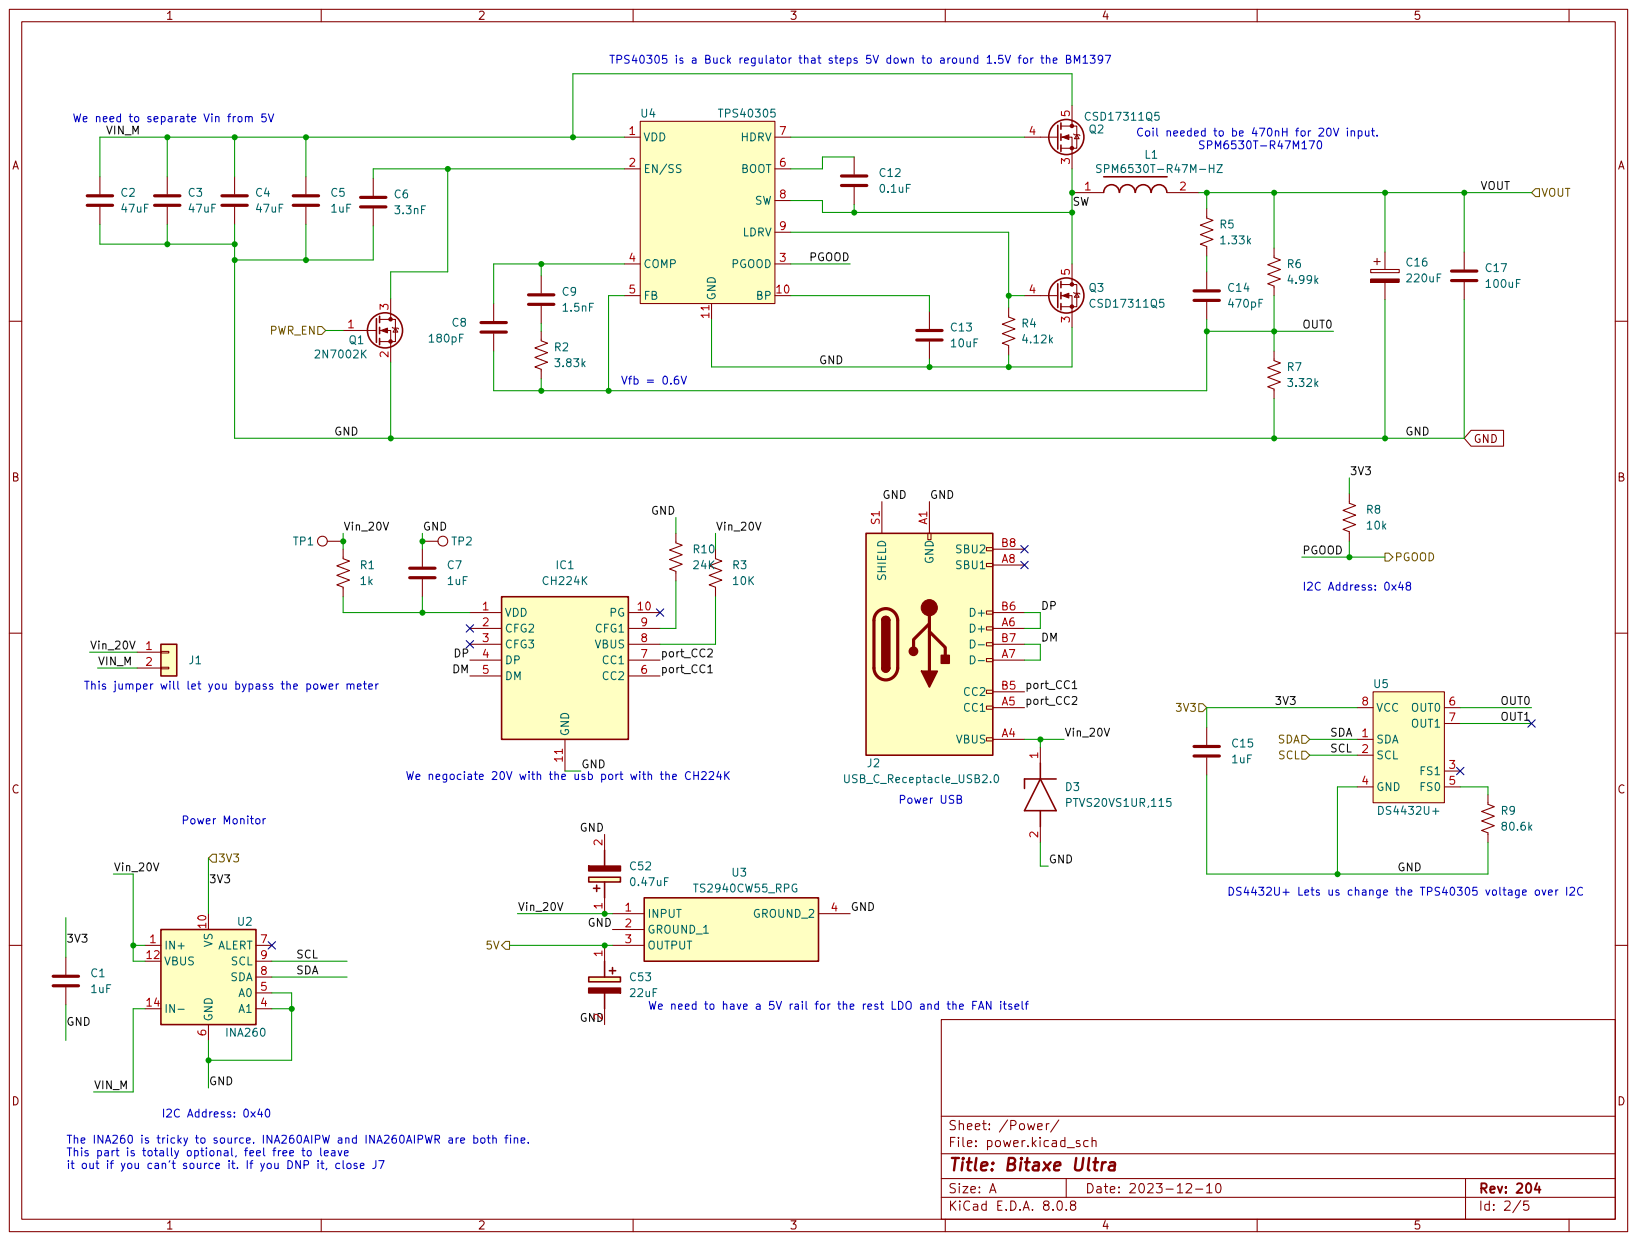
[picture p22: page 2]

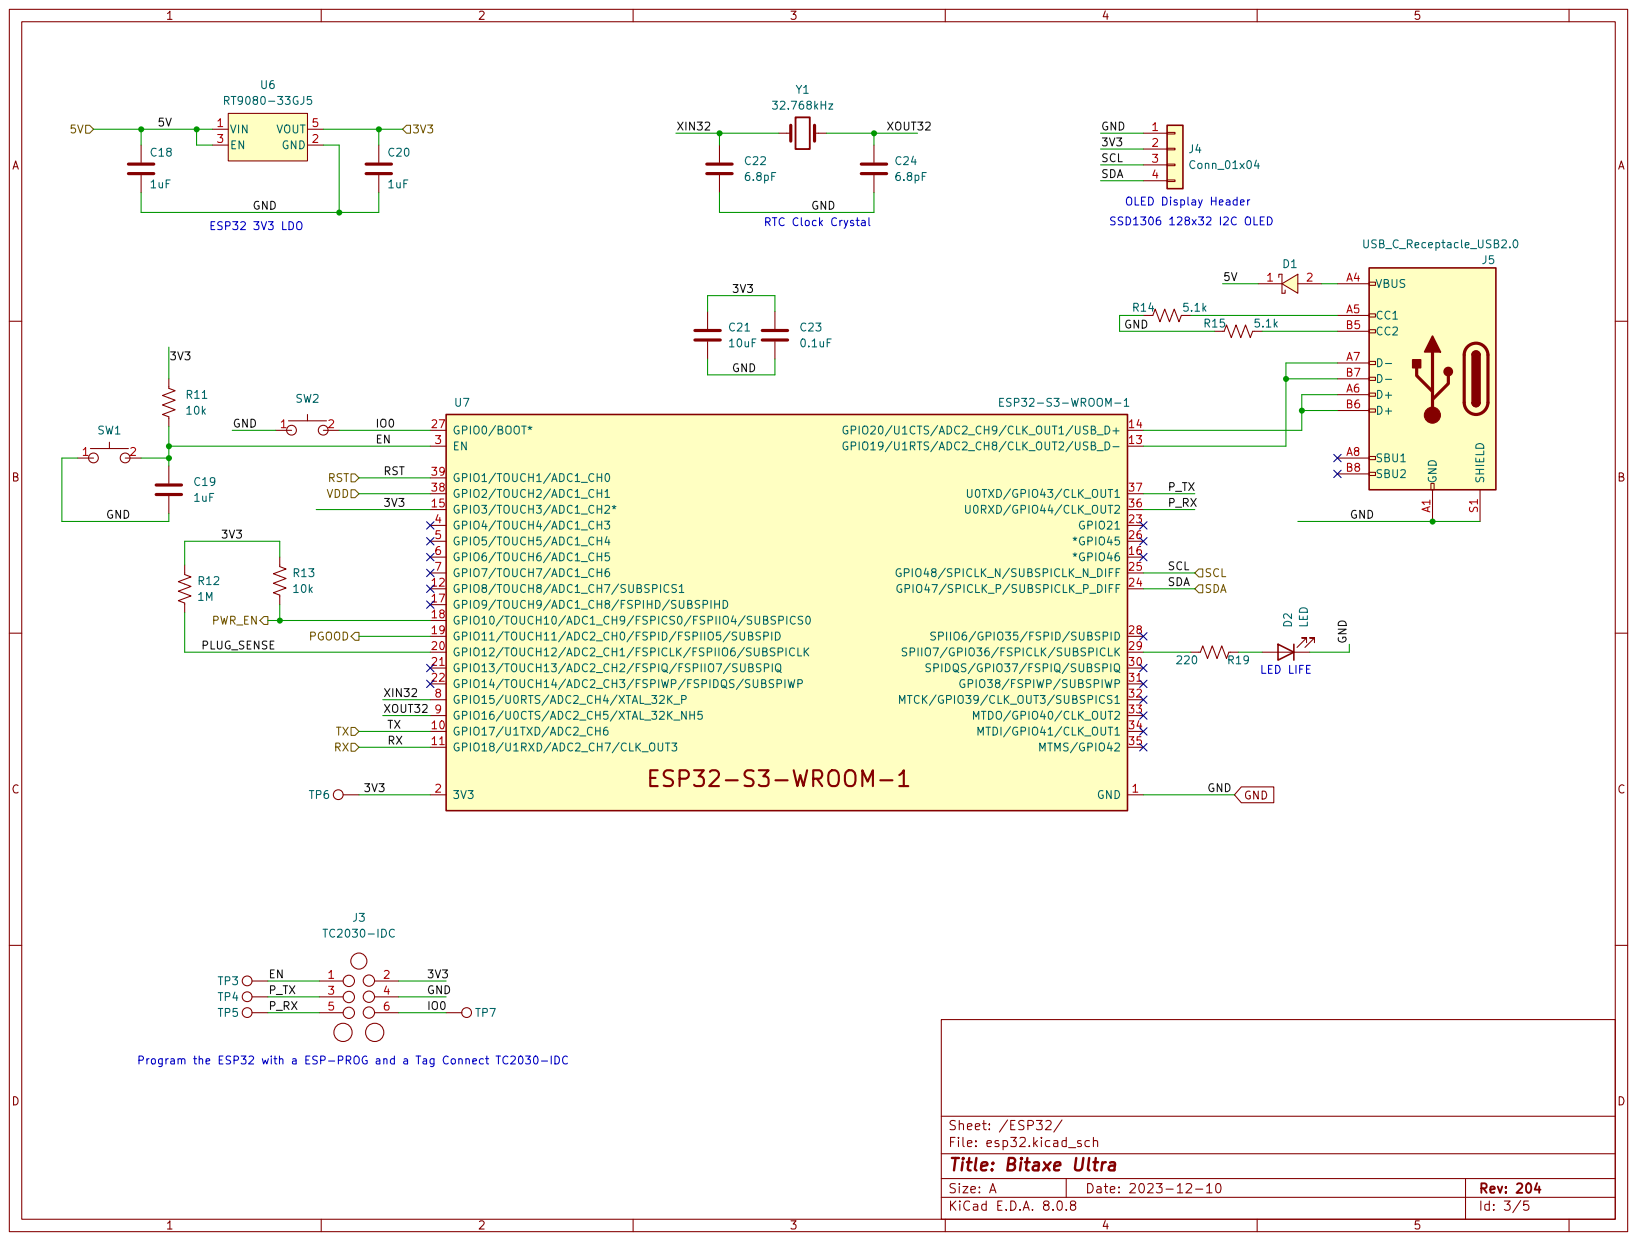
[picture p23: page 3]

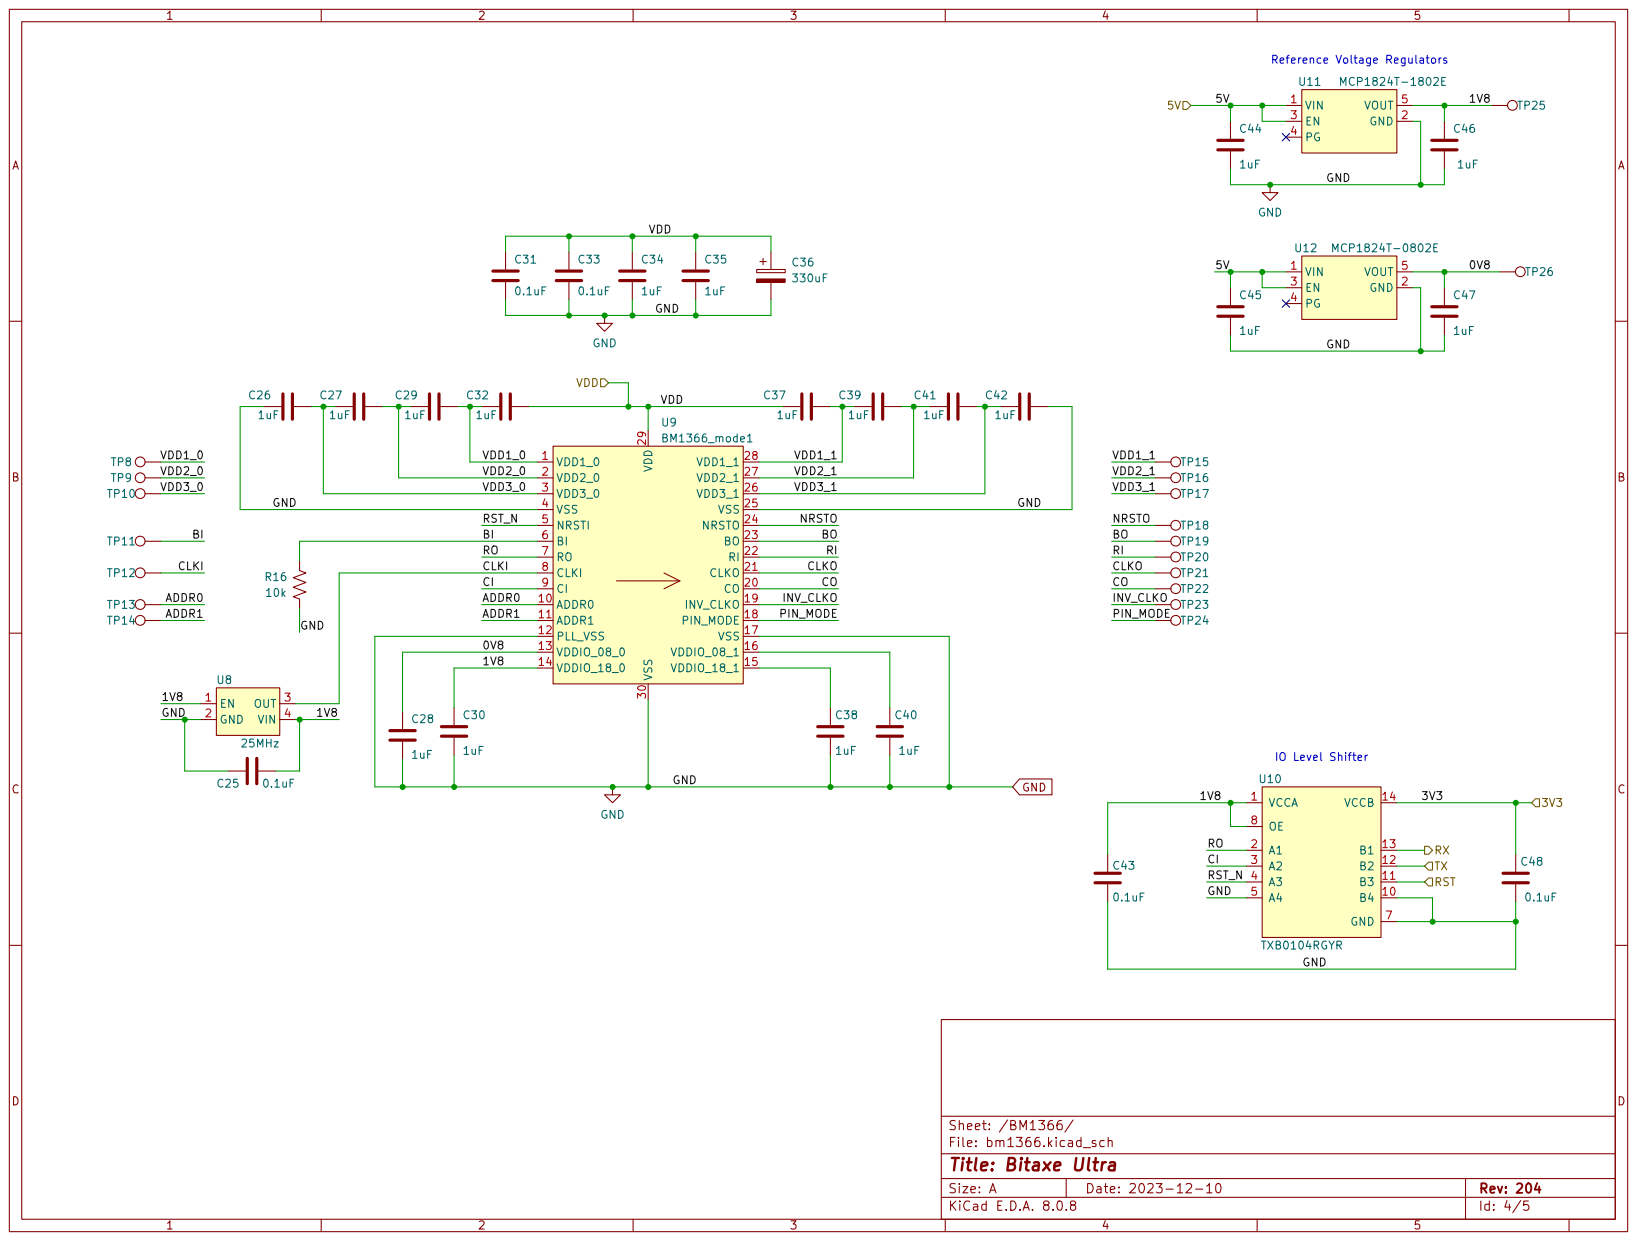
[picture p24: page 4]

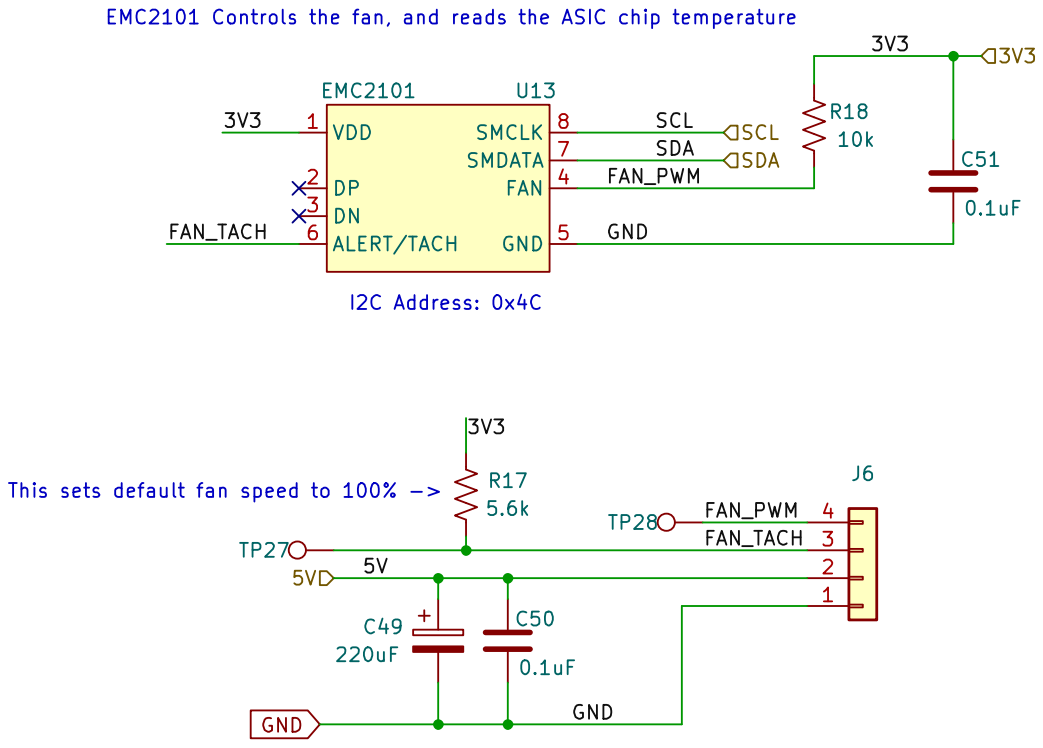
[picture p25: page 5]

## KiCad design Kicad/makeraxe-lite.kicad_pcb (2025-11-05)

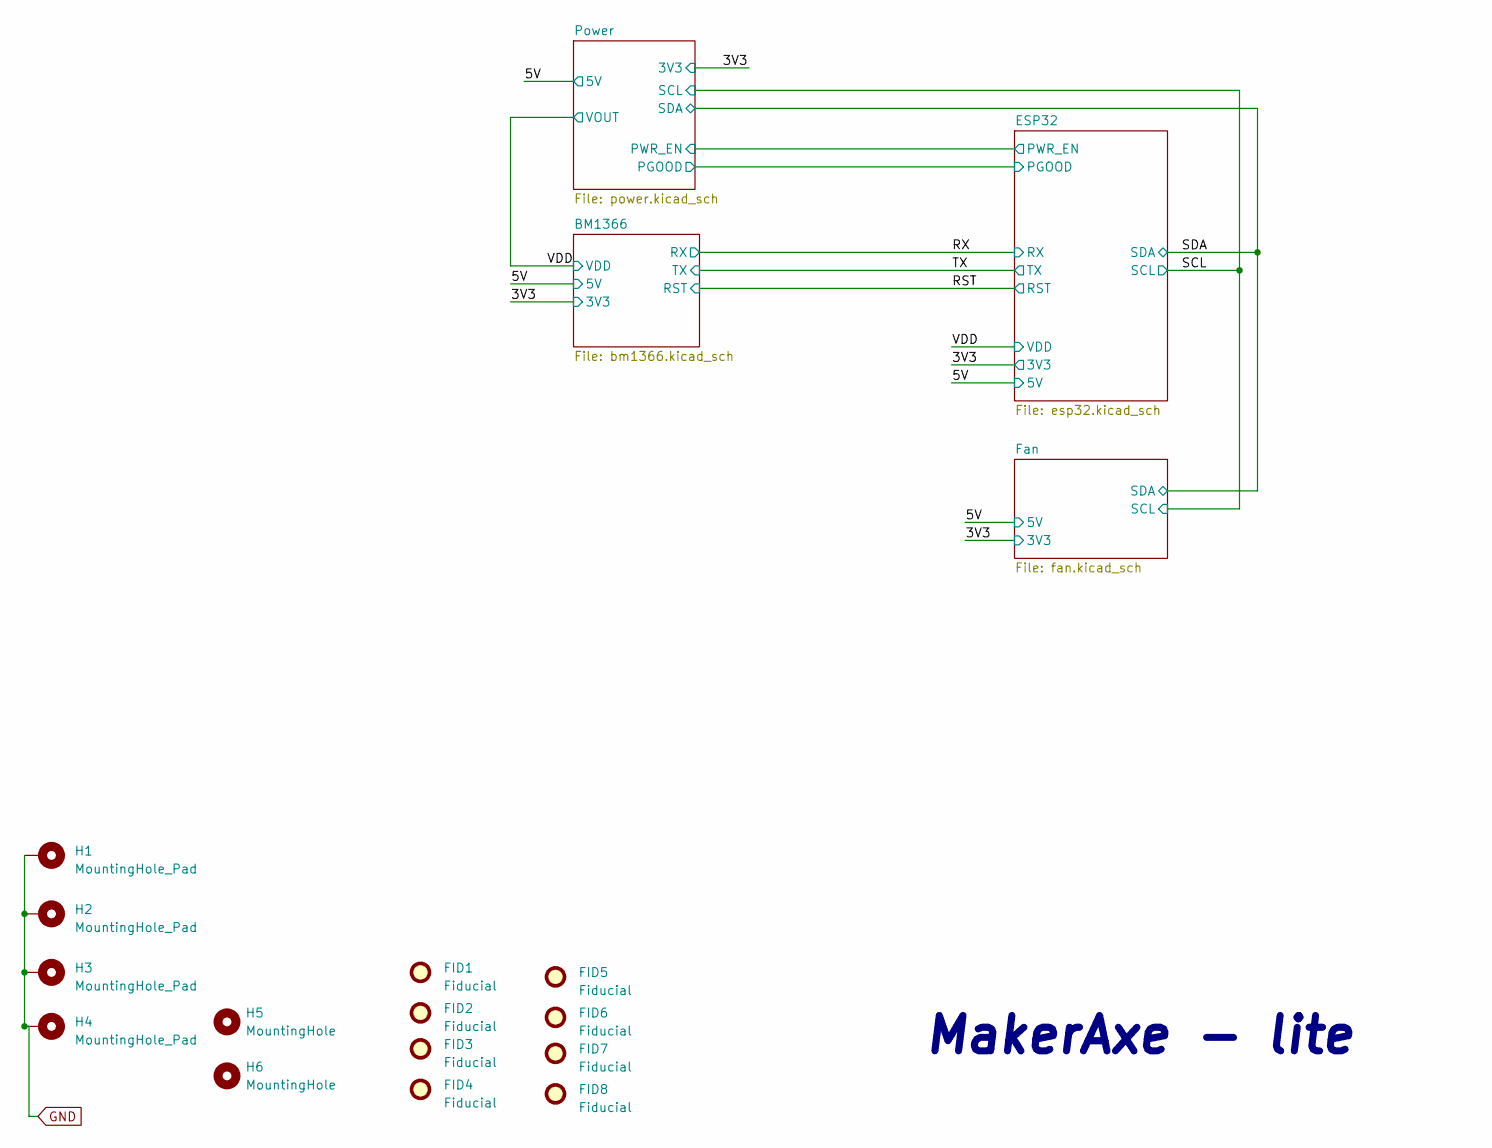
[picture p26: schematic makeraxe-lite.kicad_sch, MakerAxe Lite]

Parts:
FID1, FID2, FID3, FID4, FID5, FID6, FID7, FID8: Fiducial; Fiducial_1mm_Mask2mm
H1, H2, H3, H4: MountingHole_Pad; MountingHole_3mm_Pad_Via
H5, H6: MountingHole; MountingHole_3.5mm

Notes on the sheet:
MakerAxe - lite

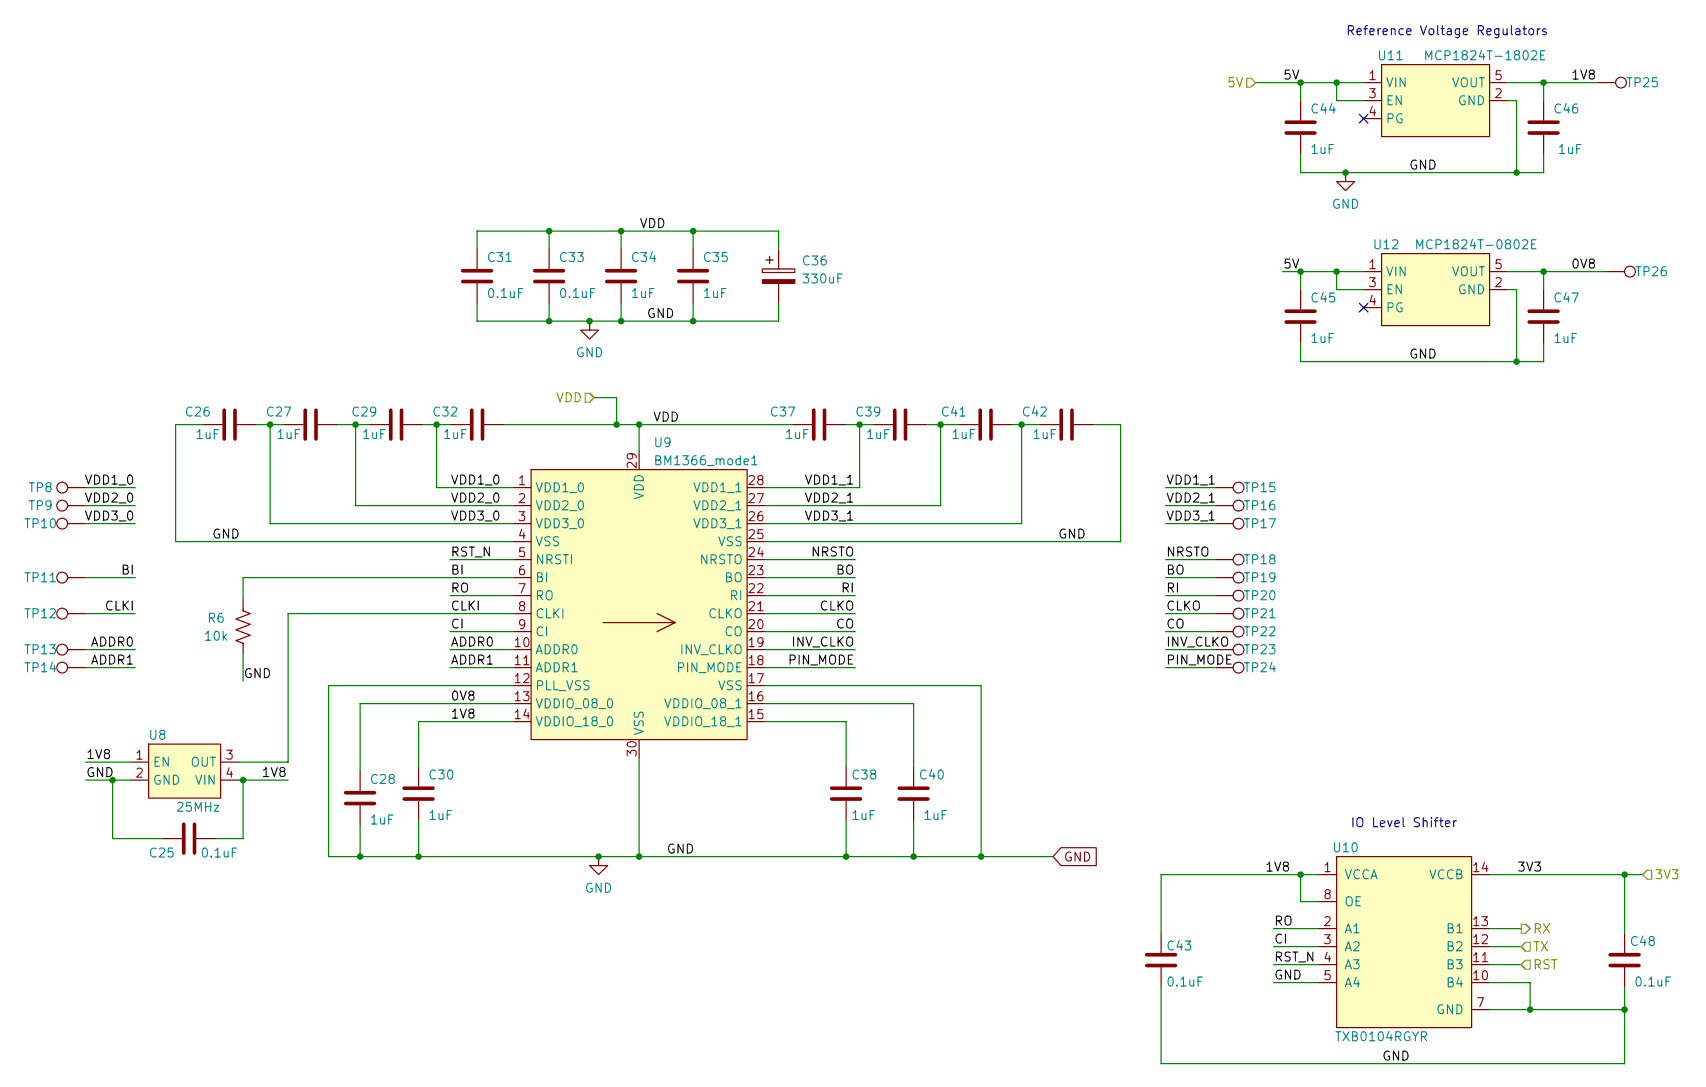
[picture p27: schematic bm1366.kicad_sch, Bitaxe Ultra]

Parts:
C25, C31, C33, C43, C48: 0.1uF; C_0402_1005Metric; PARTNO 0402X104K100CT
C26, C27, C28, C29, C30, C32, C34, C35, C37, C38, C39, C40, C41, C42, C44, C45, C46, C47: 1uF; C_0402_1005Metric; PARTNO EMK105BJ105MV-F
C36: 330uF; CP_EIA-7343-31_Kemet-D_Pad2.25x2.55mm_HandSolder; PARTNO 293D337X9010E2TE3
R6: 10k; R_0402_1005Metric; PARTNO RC0402JR-0710KL
TP8, TP9, TP10, TP11, TP12, TP13, TP14, TP15, TP16, TP17, TP18, TP19, TP20, TP21, TP22, TP23, TP24, TP25, TP26: TestPoint; TestPoint_Pad_D1.5mm
U8: 25MHz; O 25,0-JO32-B-1V3-1-T1-LF; PARTNO O 25,0-JO32-B-1V3-1-T1-LF
U9: BM1366_mode1; BM1366
U10: TXB0104RGYR; TXB0104; PARTNO TXB0104RGYR
U11: MCP1824T-1802E; SOT-23-5; PARTNO MCP1824T-1802E/OT
U12: MCP1824T-0802E; SOT-23-5; PARTNO MCP1824T-0802E/OT

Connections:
/3V3: C48.1, U10.14 (VCCB); also elsewhere on the board
/5V: C44.1, C45.1, U11.1 (VIN), U11.3 (EN), U12.1 (VIN), U12.3 (EN); also elsewhere on the board
/BM1366/0V8: C28.1, C47.1, TP26.1, U9.13 (VDDIO_08_0), U12.5 (VOUT)
/BM1366/1V8: C25.2, C30.1, C43.1, C46.1, TP25.1, U8.1 (EN), U8.4 (VIN), U9.14 (VDDIO_18_0), U10.1 (VCCA), U10.8 (OE), U11.5 (VOUT)
/BM1366/ADDR0: TP13.1, U9.10 (ADDR0)
/BM1366/ADDR1: TP14.1, U9.11 (ADDR1)
/BM1366/BO: TP19.1, U9.23 (BO)
/BM1366/CI: U9.9 (CI), U10.3 (A2)
/BM1366/CLKI: TP12.1, U8.3 (OUT), U9.8 (CLKI)
/BM1366/CLKO: TP21.1, U9.21 (CLKO)
/BM1366/CO: TP22.1, U9.20 (CO)
/BM1366/INV_CLKO: TP23.1, U9.19 (INV_CLKO)
/BM1366/NRSTO: TP18.1, U9.24 (NRSTO)
/BM1366/PIN_MODE: TP24.1, U9.18 (PIN_MODE)
/BM1366/RI: TP20.1, U9.22 (RI)
/BM1366/RO: U9.7 (RO), U10.2 (A1)
/BM1366/RST_N: U9.5 (NRSTI), U10.4 (A3)
/BM1366/VDD1_0: C29.2, C32.1, TP8.1, U9.1 (VDD1_0)
/BM1366/VDD1_1: C37.2, C39.1, TP15.1, U9.28 (VDD1_1)
/BM1366/VDD2_0: C27.2, C29.1, TP9.1, U9.2 (VDD2_0)
/BM1366/VDD2_1: C39.2, C41.1, TP16.1, U9.27 (VDD2_1)
/BM1366/VDD3_0: C26.2, C27.1, TP10.1, U9.3 (VDD3_0)
/BM1366/VDD3_1: C41.2, C42.1, TP17.1, U9.26 (VDD3_1)
/RST: U10.11 (B3); also elsewhere on the board
/RX: U10.13 (B1); also elsewhere on the board
/TX: U10.12 (B2); also elsewhere on the board
unnamed: C40.1, U9.16 (VDDIO_08_1)
unnamed: C38.1, U9.15 (VDDIO_18_1)

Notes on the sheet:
Reference Voltage Regulators
IO Level Shifter

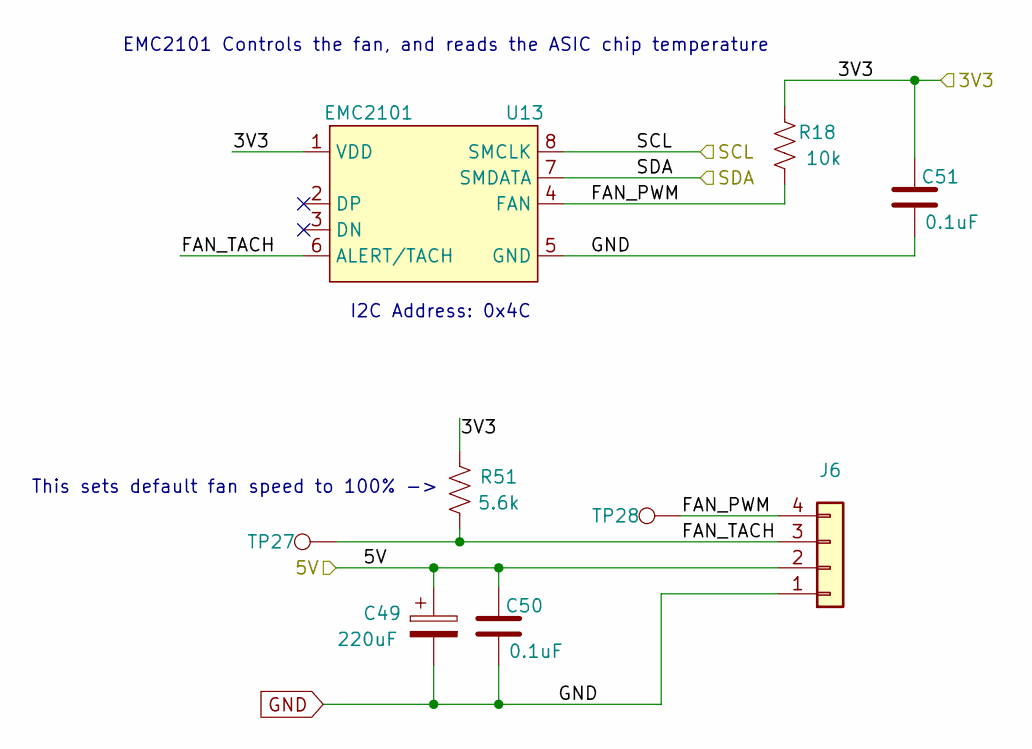
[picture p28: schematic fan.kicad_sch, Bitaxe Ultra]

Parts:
C49: 220uF; CP_Elec_6.3x7.7; PARTNO 865080345012
C50, C51: 0.1uF; C_0402_1005Metric; PARTNO 0402X104K100CT
J6: Conn_01x04; 470531000; PARTNO 0470531000
R18: 10k; R_0402_1005Metric; PARTNO RC0402JR-0710KL
R51: 5.6k; R_0402_1005Metric; PARTNO RC0402FR-135K6L
TP27, TP28: TestPoint; TestPoint_Pad_D1.5mm
U13: EMC2101; TSSOP-8_3x3mm_P0.65mm; PARTNO EMC2101-R-ACZL-TR

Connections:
/3V3: C51.1, R18.2, U13.1 (VDD); also elsewhere on the board
/5V: C49.1, C50.1, J6.2; also elsewhere on the board
/Fan/FAN_PWM: J6.4, R18.1, TP28.1, U13.4 (FAN)
/Fan/FAN_TACH: J6.3, TP27.1, U13.6 (ALERT/TACH); also elsewhere on the board
/SCL: U13.8 (SMCLK); also elsewhere on the board
/SDA: U13.7 (SMDATA); also elsewhere on the board

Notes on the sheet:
EMC2101 Controls the fan, and reads the ASIC chip temperature
This sets default fan speed to 100% ->
I2C Address: 0x4C

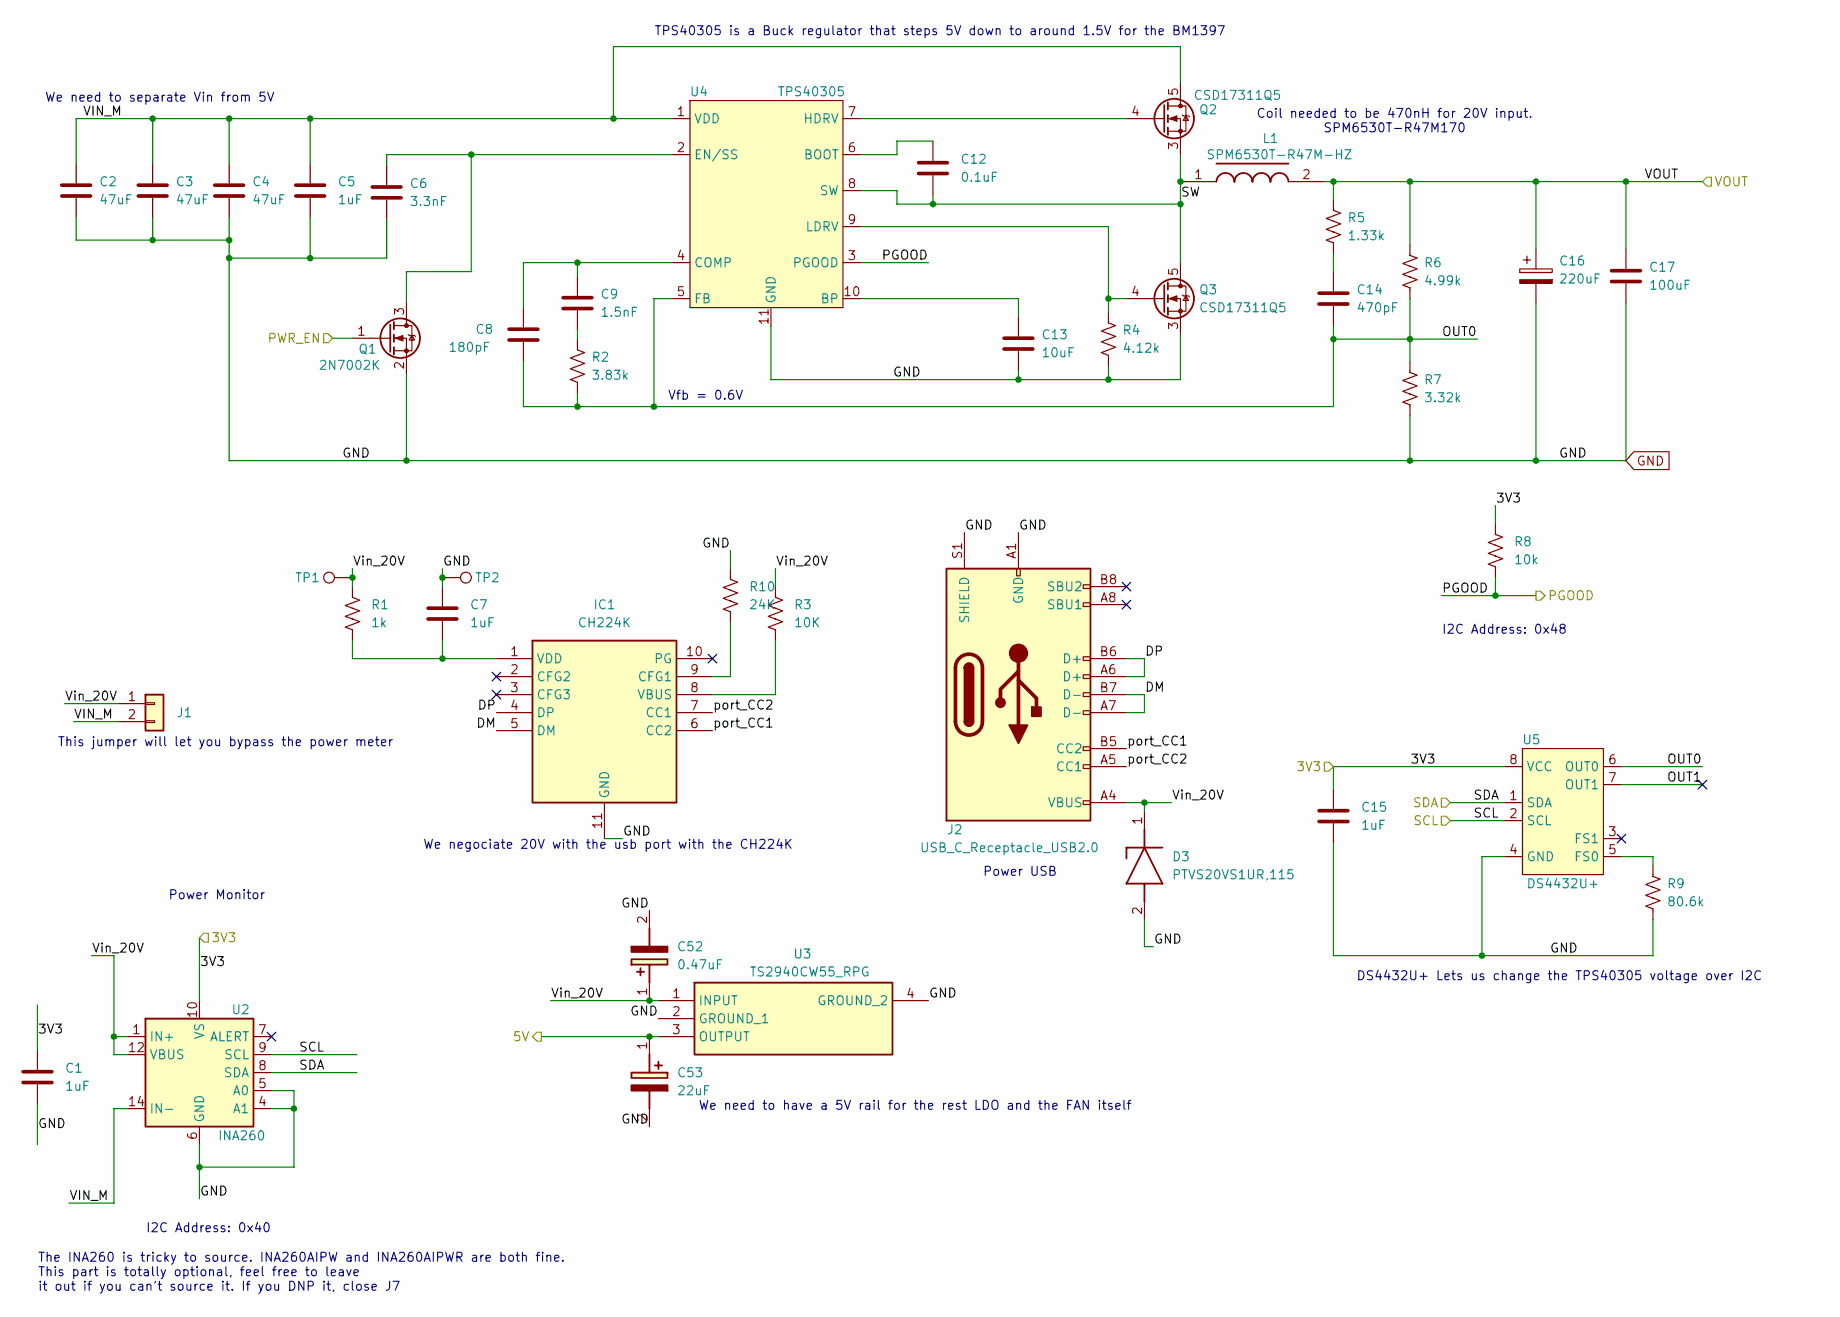
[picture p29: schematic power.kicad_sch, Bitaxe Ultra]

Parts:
C1, C15: 1uF; C_0402_1005Metric; PARTNO EMK105BJ105MV-F
C2, C3, C4: 47uF; C_1210_3225Metric; PARTNO GRM32ER61C476KE15L
C5, C7: 1uF; C_0805_2012Metric; PARTNO CL21B105KOFNNNG
C6: 3.3nF; C_0402_1005Metric; PARTNO CL05B332KB5NNNC
C8: 180pF; C_0805_2012Metric; PARTNO CC0805JRNPO9BN181
C9: 1.5nF; C_0805_2012Metric; PARTNO CC0805KRX7R9BB152
C12: 0.1uF; C_0402_1005Metric; PARTNO 0402X104K100CT
C13: 10uF; C_0805_2012Metric; PARTNO CL21A106KOQNNNE
C14: 470pF; C_0805_2012Metric; PARTNO 0805B471K500CT
C16: 220uF; CAP_2R5TPE220MAFB; PARTNO 2R5TPE220MAFB
C17: 100uF; C_1206_3216Metric; PARTNO C3216X5R0J107M160AB
C52: 0.47uF; T491A; Mouser Part Number 80-T491A474K025AT
C53: 22uF; T495C; Mouser Part Number 80-T495C226K25E300
D3: PTVS20VS1UR,115; SOD123W; Mouser Part Number 771-PTVS20VS1UR115
IC1: CH224K; SOP100P600X180-11N; Manufacturer_Part_Number CH224K
J1: Conn_01x02; PinHeader_1x02_P2.54mm_Vertical
J2: USB_C_Receptacle_USB2.0; USB_C_Receptacle_GCT_USB4105-xx-A_16P_TopMnt_Horizontal; PARTNO USB4105-GF-A
L1: SPM6530T-R47M-HZ; SPM6530; Mouser Part Number 810-SPM6530T-R47M-HZ
Q1: 2N7002K; SOT-323_SC-70; PARTNO 2N7002KW
Q2, Q3: CSD17311Q5; PARTNO CSD17311Q5
R1: 1k; R_0402_1005Metric; PARTNO RC0402FR-073K83L
R2: 3.83k; R_0402_1005Metric; PARTNO RC0402FR-073K83L
R3: 10K; R_0402_1005Metric; PARTNO RC0402FR-073K83L
R4: 4.12k; R_0402_1005Metric; PARTNO RMCF0402FT4K12
R5: 1.33k; R_0402_1005Metric; PARTNO RC0402FR-071K33L
R6: 4.99k; R_0402_1005Metric; PARTNO RC0402FR-074K99L
R7: 3.32k; R_0402_1005Metric; PARTNO RC0402FR-073K32L
R8: 10k; R_0402_1005Metric; PARTNO RC0402JR-0710KL
R9: 80.6k; R_0402_1005Metric; PARTNO RC0402FR-0780K6L
R10: 24K; R_0402_1005Metric; PARTNO RC0402FR-073K83L
TP1, TP2: TestPoint; TestPoint_Pad_D1.5mm
U2: INA260; TSSOP-16_4.4x5mm_P0.65mm; PARTNO INA260AIPW
U3: TS2940CW55_RPG; TO-263-3_TabPin2; Mouser Part Number 821-TS2940CW33RPG
U4: TPS40305; PARTNO TPS40305DRCR
U5: DS4432U+; TSSOP-8_3x3mm_P0.65mm; PARTNO DS4432U+

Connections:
/3V3: C1.1, C15.1, R8.1, U2.10 (VS), U5.8 (VCC); also elsewhere on the board
/5V: C53.1 (+), U3.3 (OUTPUT); also elsewhere on the board
/ESP32/PWR_EN: Q1.1 (G); also elsewhere on the board
/Power/DM: IC1.5 (DM), J2.A7 (D-), J2.B7 (D-)
/Power/DP: IC1.4 (DP), J2.A6 (D+), J2.B6 (D+)
/Power/OUT1: U5.7 (OUT1)
/Power/PGOOD: R8.2, U4.3 (PGOOD); also elsewhere on the board
/Power/SW: C12.2, L1.1, Q2.1, Q2.2, Q2.3 (S), Q3.5 (D), U4.8 (SW)
/Power/VIN_M: C2.1, C3.1, C4.1, C5.1, J1.2, Q2.5 (D), U2.14 (IN-), U2.15 (IN-), U2.16 (IN-), U4.1 (VDD)
/Power/Vin_20V: C52.1 (+), D3.1 (K), J1.1, J2.A4 (VBUS), J2.A9 (VBUS), J2.B4 (VBUS), J2.B9 (VBUS), R1.1, R3.1, TP1.1, U2.1 (IN+), U2.2 (IN+), U2.3 (IN+), U2.12 (VBUS), U3.1 (INPUT)
/Power/port_CC1: IC1.6 (CC2), J2.B5 (CC2)
/Power/port_CC2: IC1.7 (CC1), J2.A5 (CC1)
/SCL: U2.9 (SCL), U5.2 (SCL); also elsewhere on the board
/SDA: U2.8 (SDA), U5.1 (SDA); also elsewhere on the board
unnamed: C9.2, R2.1
unnamed: C14.1, R5.2
unnamed: IC1.9 (CFG1), R10.2
unnamed: IC1.8 (VBUS), R3.2
unnamed: C7.2, IC1.1 (VDD), R1.2
unnamed: C6.1, Q1.3 (D), U4.2 (EN/SS)
unnamed: Q2.4 (G), U4.7 (HDRV)
unnamed: Q3.4 (G), R4.1, U4.9 (LDRV)
unnamed: C12.1, U4.6 (BOOT)
unnamed: C13.1, U4.10 (BP)
unnamed: C8.1, C9.1, U4.4 (COMP)
unnamed: R9.1, U5.5 (FS0)

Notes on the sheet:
DS4432U+ Lets us change the TPS40305 voltage over I2C
I2C Address: 0x48
The INA260 is tricky to source. INA260AIPW and INA260AIPWR are both fine. This part is totally optional, feel free to leave it out if you can't source it. If you DNP it, close J7
Power Monitor
Power USB
TPS40305 is a Buck regulator that steps 5V down to around 1.5V for the BM1397
We need to have a 5V rail for the rest LDO and the FAN itself
Coil needed to be 470nH for 20V input. SPM6530T-R47M170
I2C Address: 0x40
Vfb = 0.6V
This jumper will let you bypass the power meter
We negociate 20V with the usb port with the CH224K
We need to separate Vin from 5V

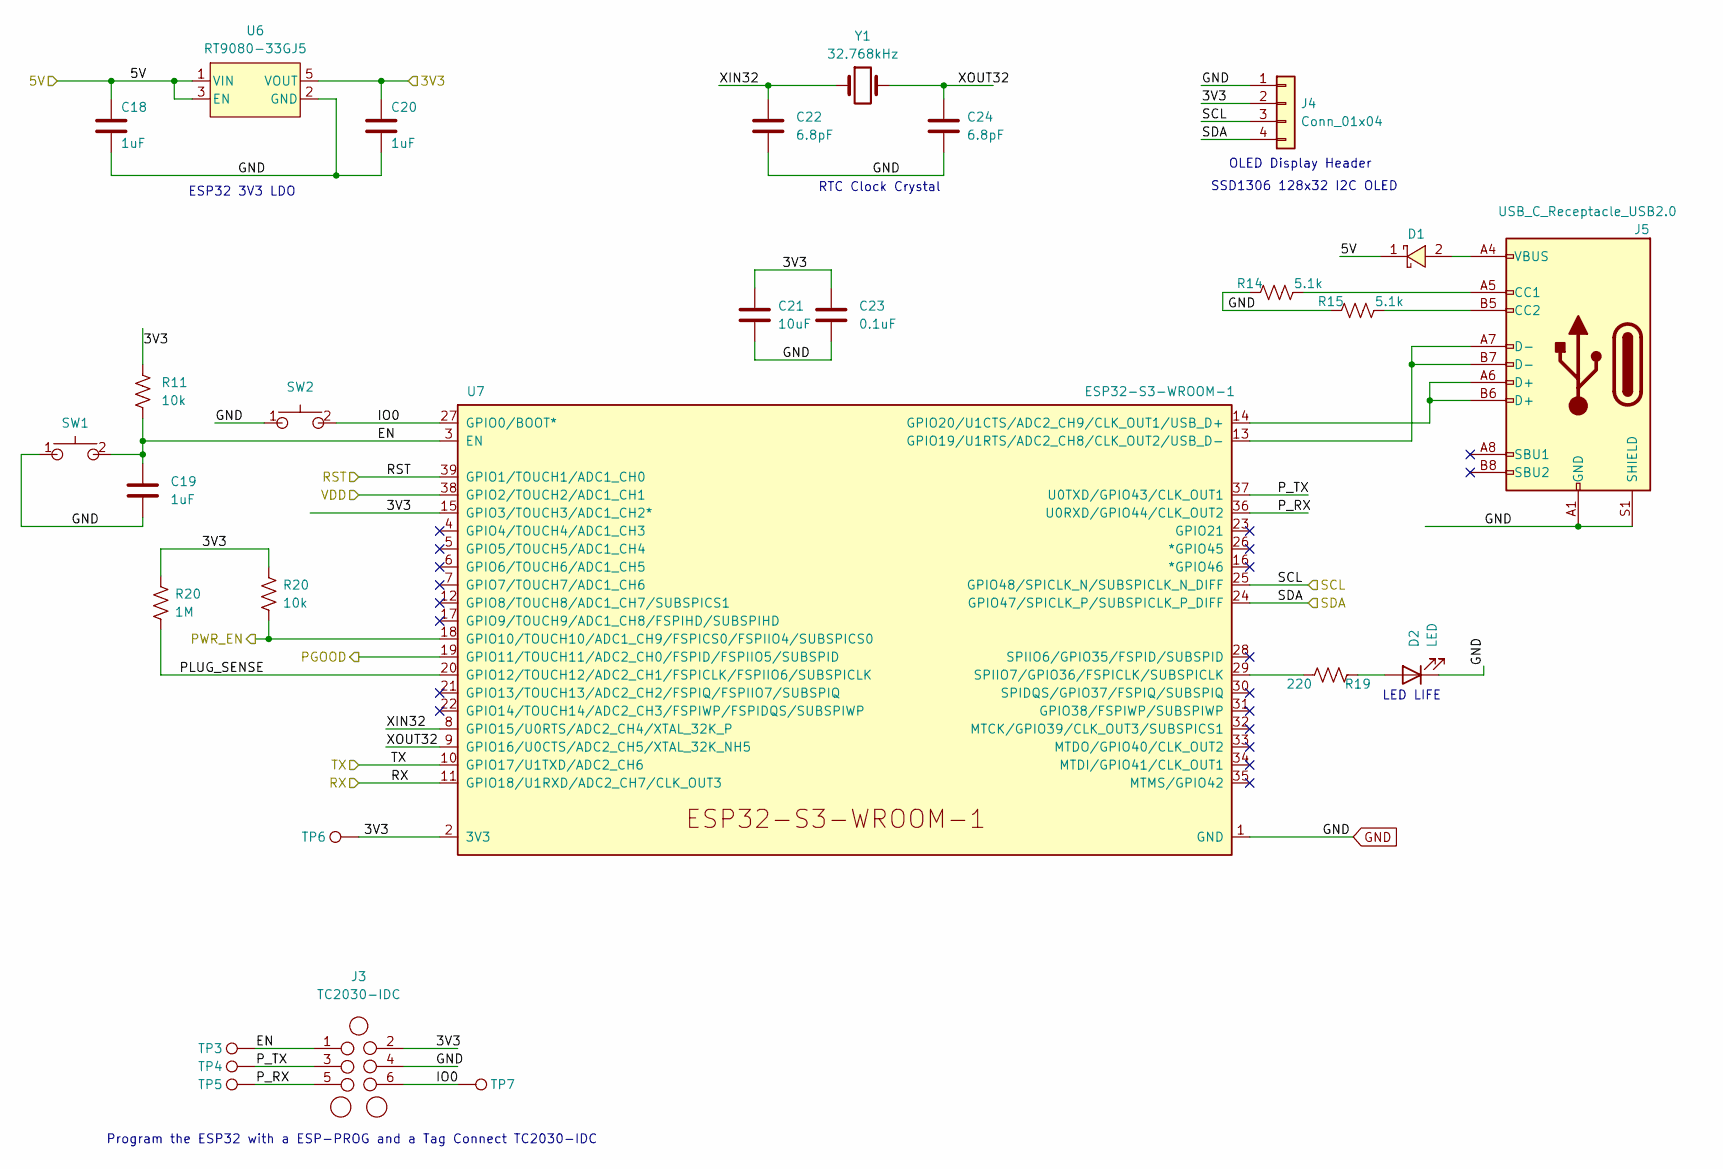
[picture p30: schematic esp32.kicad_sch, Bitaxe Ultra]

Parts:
C18, C19, C20: 1uF; C_0402_1005Metric; PARTNO EMK105BJ105MV-F
C21: 10uF; C_0805_2012Metric; PARTNO CL21A106KOQNNNE
C22, C24: 6.8pF; C_0402_1005Metric; PARTNO C0402C689C5GAC7867
C23: 0.1uF; C_0402_1005Metric; PARTNO 0402X104K100CT
D1: SS310; D_SMA; PARTNO SK310A-LTP
D2: LED; LED_0805_2012Metric_Pad1.15x1.40mm_HandSolder
J3: TC2030-IDC; Tag-Connect_TC2030-IDC-NL_2x03_P1.27mm_Vertical
J4: Conn_01x04; PinSocket_1x04_P2.54mm_Vertical_SMD_Pin1Right; PARTNO NPTC041KFXC-RC
J5: USB_C_Receptacle_USB2.0; USB_C_Receptacle_GCT_USB4105-xx-A_16P_TopMnt_Horizontal; PARTNO USB4105-GF-A
R11: 10k; R_0402_1005Metric; PARTNO RC0402JR-0710KL
R14, R15: 5.1k; R_0402_1005Metric; PARTNO RMCF0402JT5K10
R19: 220; R_0402_1005Metric; PARTNO RMCF0402JT5K10
R20: 1M; R_0402_1005Metric; PARTNO RC0402FR-071ML
SW1, SW2: GT-TC029B-H025-L1N; SW_CS1213AGF260_CRS; PARTNO CS1213AGF260
TP3, TP4, TP5, TP6, TP7: TestPoint; TestPoint_Pad_D1.5mm
U6: RT9080-33GJ5; PARTNO RT9080-33GJ5
U7: ESP32-S3-WROOM-1; PARTNO ESP32-S3-WROOM-1-N16R8
Y1: 32.768kHz; SC32S-7PF20PPM; PARTNO SC32S-7PF20PPM

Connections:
/3V3: C20.1, C21.1, C23.1, J3.2, J4.2, R11.1, TP6.1, U6.5 (VOUT), U7.2 (3V3), U7.15 (GPIO3/TOUCH3/ADC1_CH2*); also elsewhere on the board
/5V: C18.1, D1.1, U6.1 (VIN), U6.3 (EN); also elsewhere on the board
/ESP32/EN: C19.1, J3.1, R11.2, SW1.2, TP3.1, U7.3 (EN)
/ESP32/IO0: J3.6, SW2.2, TP7.1, U7.27 (GPIO0/BOOT*)
/ESP32/PLUG_SENSE: U7.20 (GPIO12/TOUCH12/ADC2_CH1/FSPICLK/FSPIIO6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); also elsewhere on the board
/ESP32/PWR_EN: U7.18 (GPIO10/TOUCH10/ADC1_CH9/FSPICS0/FSPIIO4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); also elsewhere on the board
/ESP32/P_RX: J3.5, TP5.1, U7.36 (U0RXD/GPIO44/CLK_OUT2)
/ESP32/P_TX: J3.3, TP4.1, U7.37 (U0TXD/GPIO43/CLK_OUT1)
/ESP32/XIN32: C22.1, U7.8 (GPIO15/U0RTS/ADC2_CH4/XTAL_32K_P), Y1.1
/ESP32/XOUT32: C24.1, U7.9 (GPIO16/U0CTS/ADC2_CH5/XTAL_32K_NH5), Y1.2
/Power/PGOOD: U7.19 (GPIO11/TOUCH11/ADC2_CH0/FSPID/FSPIIO5/S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); also elsewhere on the board
/RST: U7.39 (GPIO1/TOUCH1/ADC1_CH0); also elsewhere on the board
/RX: U7.11 (GPIO18/U1RXD/ADC2_CH7/CLK_OUT3); also elsewhere on the board
/SCL: J4.3, U7.25 (GPIO48/SPICLK_N/SUBSPICLK_N_DIFF); also elsewhere on the board
/SDA: J4.4, U7.24 (GPIO47/SPICLK_P/SUBSPICLK_P_DIFF); also elsewhere on the board
/TX: U7.10 (GPIO17/U1TXD/ADC2_CH6); also elsewhere on the board
unnamed: D1.2, J5.A4 (VBUS), J5.A9 (VBUS), J5.B4 (VBUS), J5.B9 (VBUS)
unnamed: D2.2 (A), R19.1
unnamed: J5.A5 (CC1), R14.2
unnamed: J5.B5 (CC2), R15.2
unnamed: J5.A7 (D-), J5.B7 (D-), U7.13 (GPIO19/U1RTS/ADC2_CH8/CLK_OUT2/USB_D-)
unnamed: J5.A6 (D+), J5.B6 (D+), U7.14 (GPIO20/U1CTS/ADC2_CH9/CLK_OUT1/USB_D+)
unnamed: R19.2, U7.29 (SPIIO7/GPIO36/FSPICLK/SUBSPICLK)

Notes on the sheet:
RTC Clock Crystal
ESP32 3V3 LDO
Program the ESP32 with a ESP-PROG and a Tag Connect TC2030-IDC
SSD1306 128x32 I2C OLED
OLED Display Header
LED LIFE

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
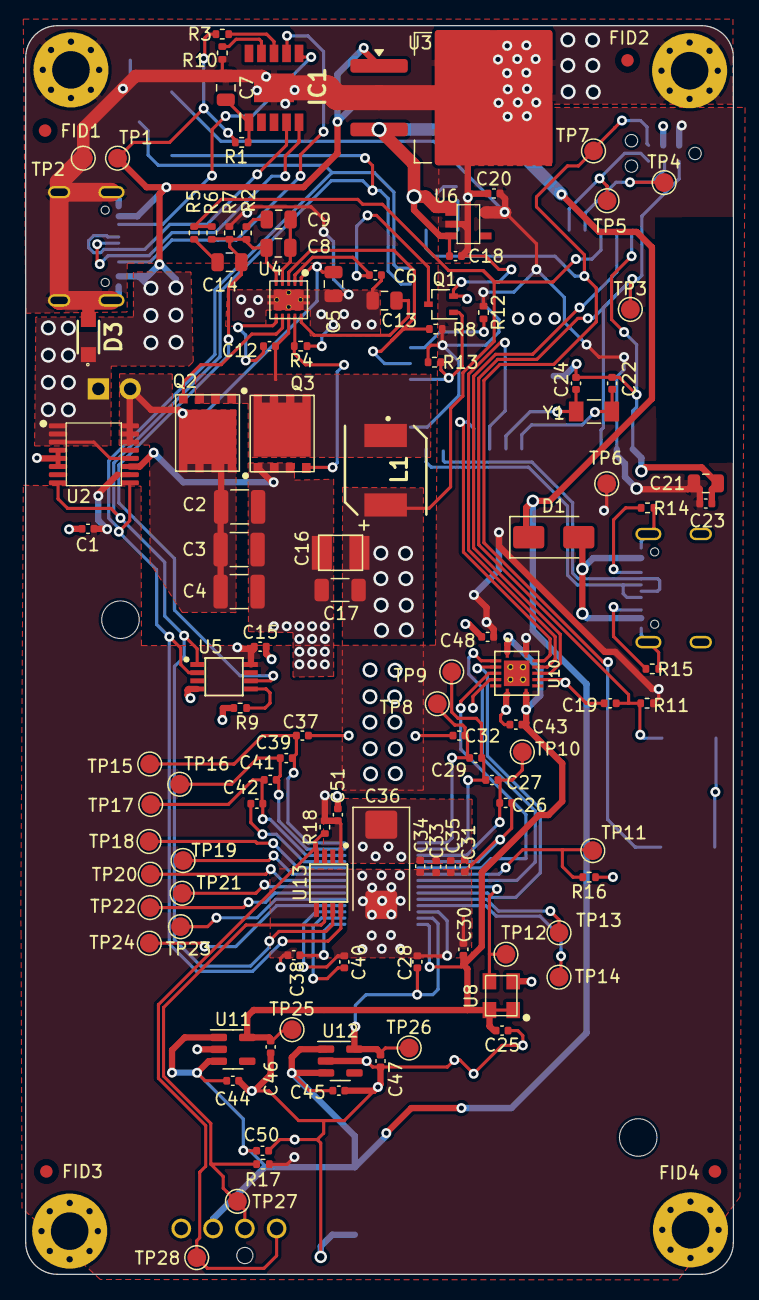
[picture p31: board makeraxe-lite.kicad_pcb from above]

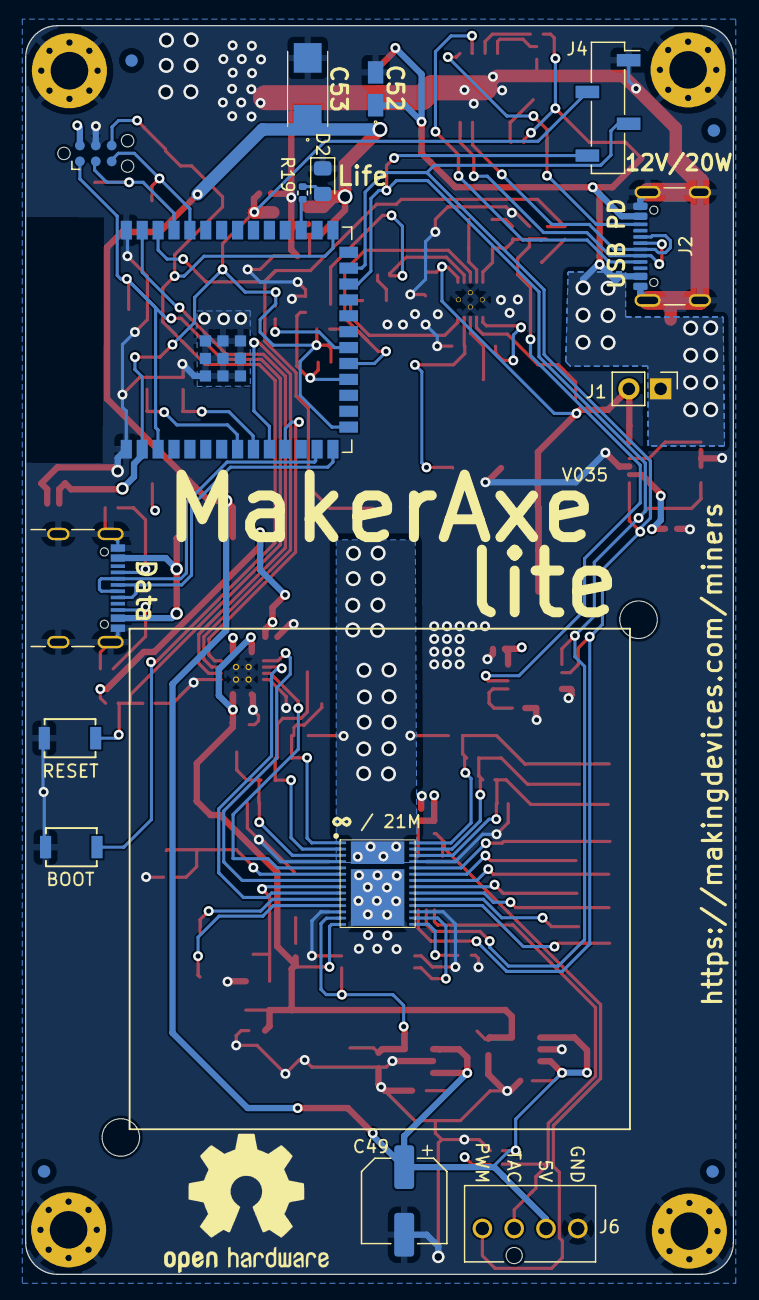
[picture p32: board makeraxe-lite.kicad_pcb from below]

Board: 2 copper layers, 56.5 x 99.8 mm, 141 parts (19 on the bottom side), 71 nets.

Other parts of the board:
R12: 1M; R_0402_1005Metric
R13, R16: 10k; R_0402_1005Metric
R17: 5.6k; R_0402_1005Metric

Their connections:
/3V3: R12.1, R13.1, R17.2; also elsewhere on the board
/ESP32/PLUG_SENSE: R12.2; also elsewhere on the board
/ESP32/PWR_EN: R13.2; also elsewhere on the board
/Fan/FAN_TACH: R17.1; also elsewhere on the board

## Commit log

2024-12-18 cleaning and releasing a new v0.25 board
    [21-0164B_L622-1_MXM.step, 2R5TPE220MAFB.step, 470531000.stp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]
2024-12-19 Updating Bill Of Materials
    [BoM_makeraxelitev025.xlsx, esp32.kicad_sch, makeraxe-lite.kicad_sch]
2024-12-26 Update to readme
    [BoM_makeraxelitev025.xlsx]
2024-12-26 Link the gerber files
2024-12-29 update new readme
    [BoM_makeraxelitev025.xlsx]
2024-12-30 update ibom and pcb3d
2025-11-05 V0.35 Release
    [BoM_makeraxelitev025.xlsx, BoM_makeraxelitev035.xlsx, T491A474K025AT7280.stp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]

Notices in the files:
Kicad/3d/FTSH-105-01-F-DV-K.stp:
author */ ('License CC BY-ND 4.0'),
